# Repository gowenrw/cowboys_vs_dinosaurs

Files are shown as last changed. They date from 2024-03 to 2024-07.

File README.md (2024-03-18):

# cowboys_vs_dinosaurs

Cowboys vs Dinosaurs Badge Artifacts

This is a DEFCON Indie badge created for DC32.

This is where all the files for the Badge will be stored.

This includes code and art and cad and fab files.  All the things.

## File Structure

This is the file structure of this repository

* [/](/README.md) - YOU ARE HERE
* [/art/](./art/) - Artwork and other graphics created by this project
  * [/art/inspiration/](./art/inspiration/) - Art and graphics pulled f6 other sources used as inspiration for this project
  * [/art/fonts/](./art/fonts/) - Fonts used in art and graphics
* [/code/](./code/) - All project related Code / Firmware
* [/docs/](./docs/) - Documentation created by this project including web pages
* [/eda/](./eda/) - Electronic Design Automation files (i.e. KiCad)
  * [/eda/cowboys_vs_dinos/](./eda/cowboys_vs_dinos/) - KiCad 7.x project folder for the cowboys_vs_dinos PCB
* [/reference_parts/](./reference_parts/) - Documentation pulled from other sources related to components
* [/README.md](/README.md) - This File
* [/LICENSE](/LICENSE) - Currently set to MIT

Note: the reference_parts directory is a link to a submodule repository.
To add it use the following cmd after cloning this:
```
git submodule update --init --recursive
```
If adding for the first time (i.e., it is not linked in the remote master) use this:
```
git submodule add https://github.com/gowenrw/reference_parts reference_parts
```
This will make a link to the current commit of that repo.
To update it to a newer commit after its been added use this cmd:
```
git submodule update --remote
```

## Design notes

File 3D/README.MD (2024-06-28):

# 3D Files

## Badge bumper

The badge bumper is a simple 3d print that sandwiches between the two PCBs. It is designed to press onto the standoff nuts to keep it in place.

This bumper provides a few useful features:
- Prevents things from dropping into the well of the badge
- When printed with a translucent material, allows for diffusion of the LED lights

When printing, we currently recommend a low infill, around 5%, and a recilinear infill or similar geometry as opposed to infill such as Gyroidal which will diffuse too much light internally.

We do not have specific print settings for this, but the part is designed to print as easily as possible.

-@hon1nbo

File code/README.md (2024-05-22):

# Code

This is where all the project related Code / Firmware is located

# File Structure

This is the file structure of this repository

* [/](/README.md) - Home
* [/code/](/code/) - YOU ARE HERE

# Arduino IDE/CLI

The code presented here is mostly Arduino code.

In order to use this code and push new code to the ESP32 on the badge we recommend using the Arduino IDE/CLI software.
This can be downloaded for various platforms at [arduino.cc](https://www.arduino.cc/en/software).

The Arduino IDE UI will require some manual configuration to work with the badge ESP32 and our code.

The Arduino CLI can be used instead and allows for scripting much of the initial setup and use of whichever IDE you like (in my case I use VSCode).

# Arduino Versions

These are the Arduino IDE and CLI versions we have tested the code with:

* Arduino IDE v 2.3.2
  * [Windows MSI Link](https://downloads.arduino.cc/arduino-ide/arduino-ide_2.3.2_Windows_64bit.msi)
  * [Linux 64bit AppImage Link](https://downloads.arduino.cc/arduino-ide/arduino-ide_2.3.2_Linux_64bit.AppImage)
  * [MacOS ARM64bit DMG Link](https://downloads.arduino.cc/arduino-ide/arduino-ide_2.3.2_macOS_arm64.dmg)
  * [Installation Instructions](https://docs.arduino.cc/software/ide-v2/tutorials/getting-started/ide-v2-downloading-and-installing)
* Arduino CLI v 0.35.3
  * [Windows MSI Link](https://github.com/arduino/arduino-cli/releases/download/v0.35.3/arduino-cli_0.35.3_Windows_64bit.msi)
  * [Linux 64bit Tarball Link](https://github.com/arduino/arduino-cli/releases/download/v0.35.3/arduino-cli_0.35.3_Linux_64bit.tar.gz)
  * [MacOS ARM64bit Tarball Link](https://github.com/arduino/arduino-cli/releases/download/v0.35.3/arduino-cli_0.35.3_macOS_ARM64.tar.gz)
  * [Installation Instructions](https://arduino.github.io/arduino-cli/0.35/installation/)

# Quickstart

If you want to jump right in and start compiling and uploading code using the Arduino CLI and the scripts provided then checkout the [QUICKSTART page](QUICKSTART.md).

# Arduino IDE setup and use

Some additional setup is required to use the Arduino IDE with the ESP32 on the badge:

* Add the ESP32 boards manager URL in preferences
  * Under File->Preferences find the "Additional boards manager URLs" section and add the following
  * https://espressif.github.io/arduino-esp32/package_esp32_index.json
  * Then click OK and close the IDE.  When it is reopened it wil download the ESP32 board definitions.
* Select the board "ESP32 Dev Module"
  * You need to select a board to associate with the code even if that board is not connected
  * In the "Select Board" dropdown, choose "ESP32 Dev Module" from the list
  * The first time you do this it may download some addiotional software.
* Connect the ESP32 via USB cable and select the COM port if it is not autodetected
  * In most cases it should autodetect the port
  * Sometimes on first connect you need to help it by going to Tools->Port and choosing the port
* This code exceeds the normal partition size so make sure you select the Minimal SPIFFS Partition type
  * This setting can be found under Tools -> Partition Scheme
* This code uses the AdaFruit NeoPixel library which needs to be installed
  * The library can be installed via the Arduino IDE library manager or manually
  * Installation instructions can be found at [the adafruit neopixel github page](https://github.com/adafruit/Adafruit_NeoPixel)

Once the Arduino IDE environment has been set up you can simply open one of the sketches here, make whatever changes you like, then compile and upload the code to the badge.

# Arduino CLI

In an effort to bring portability to the code here (since this is lacking in the Arduino 2.x IDE) we will be providing a local configuration file for the Arduino CLI and scripts to make use of it.

While we cannot ensure this will work on all systems, the files provided should at a minimum help you configure your local environment.

## Using the CLI Local Config

The arduino cli will use a global default config if a config file is not specified.

A local config file is provided named ```arduino-cli.yml``` which uses relative path references for the data and staging and build and user area that Arduino CLI should use.

These directories are local to the repository code directory and the CLI will install all its needed files here instead of in the various places it usually defualts to on differnt systems.

While this might duplicate many files on your system if they are already installed in default locations, it provides a consistent cross platform way of knowing exactly what libraries, headers, etc., that Arduino will use in the compilation of your code.

NOTE that the .gitignore for this repository has been set up to ignore the local directories used to store the core and library files to prevent these files from accidentally getting uploaded to github.

To use the Arduino CLI with this local config file simply add the ```--config-file arduino-cli.yml``` argument to each CLI command.

For example, the command below uses the local config file and will dump the current config to the screen
```
arduino-cli --config-file arduino-cli.yml config dump
```

## Setup for CLI

There are a few things that need to be done to setup the Arduino CLI for use with the badge ESP32 and our code.

The ESP32 board core files must be loaded as well as any libraries the code will use.

To simplify this setup we have created setup bash script named ```cli-setup.sh``` that can be run on Linux and Windows (via Git Bash for Windows).

To perform the CLI setup via the script execute it in the code directory
```
bash ./cli-setup.sh
```

This script will save any std_out and std_err output to a file named ```arduino_cli_setup.log``` which you can review if you are having issues.

To perform the CLI setup manually without this script you can use the commands outlined below.

### Installing the ESP32 board core for CLI

Since the config is specifying a third party core for the ESP32 we need to pull an initial index from it.  This search command will pull that index.
```
arduino-cli --config-file arduino-cli.yml core search esp32
```

Next we need to install the ESP32 board core files using this command.
```
arduino-cli --config-file arduino-cli.yml core install esp32:esp32
```

If the ESP32 board core files were already installed the above will simply say already installed.

To update the core file indexs to check for newer versions of previously installed cores, use the following command
```
arduino-cli --config-file arduino-cli.yml core update-index
```

To upgrade any previously installed cores use the following command
```
arduino-cli --config-file arduino-cli.yml core upgrade
```

### Installing the Neopixel Library

This code uses the AdaFruit NeoPixel library which needs to be installed

If this is the first time we are installing a library we will need the indexes so this search command will get them
```
arduino-cli --config-file arduino-cli.yml lib search 'Adafruit NeoPixel'
```

Next we need to install the Adafruit NeoPixel library files with this command
```
arduino-cli --config-file arduino-cli.yml lib install 'Adafruit NeoPixel'
```

If the Adafruit NeoPixel library files were already installed the above will simply say already installed.

To upgrade a previously installed version of this library use the following command
```
arduino-cli --config-file arduino-cli.yml lib upgrade 'Adafruit NeoPixel'
```

### Installing Other Libraries

In addition to the Neopixel Library above the CTF portion of our code requires a few more libraries.

These should be installed using the same steps as above.

This is the list of additional libraries needed

* "AsyncTCP"
* "ESPAsyncWebSrv"
* "DNSServer"

## Connect badge ESP32 board via CLI

The following command will dump a list of all available board cores installed
```
arduino-cli --config-file arduino-cli.yml board listall
```

Make sure the ESP32 we are using on the badge is in that list
```
  ESP32 Dev Module                 esp32:esp32:esp32
```

If it is not then retry the CLI setup to install the core files.

Next we will connect the badge ESP32 to our machine using a USB C cable
and check if the CLI can see it.

The following command will list all the connected boards the CLI sees
```
arduino-cli --config-file arduino-cli.yml board list
```

This will show the detected COM port and board type (which may be Unknown)
```
  Port Protocol Type                Board Name FQBN Core
  COM4 serial   Serial Port (USB)   Unknown
```

Don't worry if the board FQBN shows up as Unknown since we can set that

Take note of the COM port since we will need that to communicate with it later

## Compile code via CLI

At this point we should be ready to compile and upload code to the badge ESP32 board.

In the following examples we will be referencing the sketch ```cvd_02``` code so you will need to change this for whichever sketch you wish to use.

The following command will compile the named sketch for use with our board fqbn
```
arduino-cli --config-file arduino-cli.yml compile --fqbn esp32:esp32:esp32 --build-path _build --export-binaries cvd_02 --build-property build.partitions=min_spiffs --build-property upload.maximum_size=1966080
```

The arg ```--build-path _build``` is optional to have it put all build artifacts here instead of temp for ease of troubleshooting.

The arg ```--export-binaries``` will save the final binary files into ```<sketch_name>/build/<fqbn>/``` for use by upload.

The build property args ```--build-property build.partitions=min_spiffs --build-property upload.maximum_size=1966080``` make sure that the partition size and upload size are set properly.
Our code is THIC and wont fit in the default partition size.

When the CLI compile is run it should show you compile stats and/or errors similar to this
```
  Sketch uses 1827197 bytes (92%) of program storage space. Maximum is 1966080 bytes.
  Global variables use 48884 bytes (14%) of dynamic memory, leaving 278796 bytes for local variables.
  Maximum is 327680 bytes.
  Used library        Version Path
  Adafruit NeoPixel   1.11.0  .\code\libraries\Adafruit_NeoPixel
  WiFi                2.0.0   .\code\_data\packages\esp32\hardware\esp32\2.0.11\libraries\WiFi
  AsyncTCP            1.1.4   .\code\libraries\AsyncTCP
  DNSServer           2.0.0   .\code\_data\packages\esp32\hardware\esp32\2.0.11\libraries\DNSServer
  ESPAsyncWebSrv      1.2.6   .\code\libraries\ESPAsyncWebSrv
  FS                  2.0.0   .\code\_data\packages\esp32\hardware\esp32\2.0.11\libraries\FS
  Used platform Version Path
  esp32:esp32   2.0.11  .\code\_data\packages\esp32\hardware\esp32\2.0.11
```

### Script to Compile code via CLI

To simplify the above we have created a bash script named ```cli-compile.sh``` that takes a single command line argument of the sketch name.

To perform the compile via the script execute it in the code directory
```
bash ./cli-compile.sh cvd_02
```

## Upload code via CLI

Now we are ready to upload the binary we compiled to the badge ESP32 board.

Note that the binary file needed is saved to ```<sketch_name>/build/<fqbn>/``` and will be named ```<sketch_name>.ino.bin```
The code we have written here may include binaries which can be used without compiling and if you make changes and compile then these files should be overwritten.

The following command will upload the named sketch binary to the badge
```
arduino-cli --config-file arduino-cli.yml upload -p COM4 --fqbn esp32:esp32:esp32 --input-file cvd_02/build/esp32.esp32.esp32/cvd_02.ino.bin
```

NOTE: Saving the compiled binary in a defined place and uploading from an input file allows for quickly changing between different code without the need to compile each again.

It should show you upload stats and/or errors
```
  esptool.py v4.5.1
  Serial port COM4
  Connecting....
  Chip is ESP32-D0WD-V3 (revision v3.0)
  Features: WiFi, BT, Dual Core, 240MHz, VRef calibration in efuse, Coding Scheme None
  Crystal is 40MHz
  MAC: a8:42:e3:47:f0:50
  Uploading stub...
  Running stub...
  Stub running...
  Changing baud rate to 921600
  Changed.
  Configuring flash size...
  Flash will be erased from 0x00001000 to 0x00005fff...
  ...
  Compressed 18960 bytes to 13073...
  Writing at 0x00001000... (100 %)
  Wrote 18960 bytes (13073 compressed) at 0x00001000 in 0.3 seconds (effective 538.9 kbit/s)...
  Hash of data verified.
  ...
  Compressed 732656 bytes to 475614...
  Writing at 0x00010000... (3 %)
  Writing at 0x0001c1bd... (6 %)
  ...
  Writing at 0x000bcec0... (96 %)
  Writing at 0x000c2b72... (100 %)
  Wrote 732656 bytes (475614 compressed) at 0x00010000 in 6.3 seconds (effective 925.8 kbit/s)...
  Hash of data verified.
  Leaving...
  Hard resetting via RTS pin...
```

### Script to Upload code via CLI

To simplify the above we have created a bash script named ```cli-upload.sh``` that takes two command line arguments of the sketch name and serial port.

To perform the compile via the script execute it in the code directory
```
bash ./cli-upload.sh cvd_02 COM4
```

## Monitor Serial Output

To monitor the serial output you can use the arduino-cli or your favorite serial app.

The following command will list all the connected boards so you can get the serial port
```
arduino-cli --config-file arduino-cli.yml board list
```

The arduino-cli monitor command with serial port (from above) and baud config can be used like this:
```
arduino-cli monitor --port COM4 --config baudrate=115200
```

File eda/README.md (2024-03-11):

# Electronic Design Automation

This is where all the Electronic Design Automation files for the PCB(s) will be stored.
The EDA used is KiCad 7.x unless otherwise specified.

The KiCad projects have been configured to use local libraries for long term sustainability per the best practices listed [HERE](https://hackaday.com/2017/05/18/kicad-best-practises-library-management/) and elsewhere.

## File Structure

This is the file structure of this repository

* [/](/README.md) - Home
* [/eda](/eda/) - YOU ARE HERE
  * /eda/<project>/ - KiCad project folder for the named project PCB(s)
    * ./3d_models/ - This directory contains footprint 3d model files
    * ./gerber/ - This directory contains gerber formatted files for manufacturing
    * ./lib_fp/ - This directory contains footprint module directories
    * ./lib_sh/ - This directory contains schematic library files
    * ./snapshots/ - This directory contains prints of schematic / cad files and images of preview / final product

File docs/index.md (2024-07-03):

---
layout: default
---

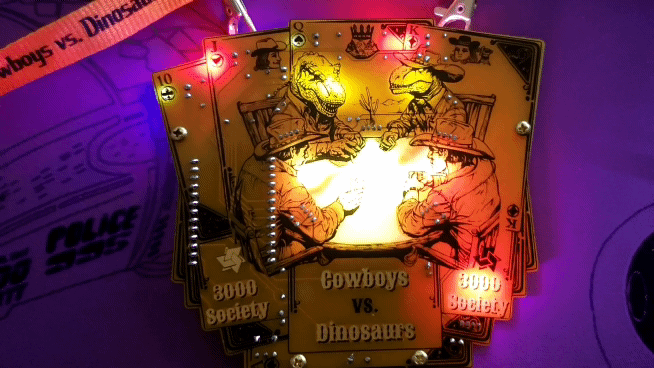
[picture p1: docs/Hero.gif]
Hero Image


# Cowboys vs Dinosaurs Badge

Welcome to the Cowboys vs Dinosaurs Badge website.

This badge was designed for the 3000 Society conference in May 2024.
It will also be made available at the DEFCON 32 conference in Aug 2024.

On this page you will find all the details about this badge including an operations guide, an assembly guide (for those building the badge from a kit), and a detailed review of the art and cicuit design and pcb design.

-- [@alt_bier](https://twitter.com/alt_bier)  - [My Contact Info](https://gowen.net/about)

---

Touch Image

# Details

The badge theme was based on the 3000 Society conference theme of "Cowboys vs Dinosaurs".
Since this is a gaming conference I thought it was apppropriate to have them facing off at a card game with a playing card background.

This badge includes an ESP32 Wemos Lolin32 development board, six neopixel addressable LEDs, six traditional one color LEDs, and five capacitive touch areas, all powered by a LIPO battery.

Since the ESP Dev board has an embedded battery charge circuit the schematic for the badge is fairly simple.
The PCB layout and tracing was a challenge due to all the solder mask voids and capacitive touch areas.

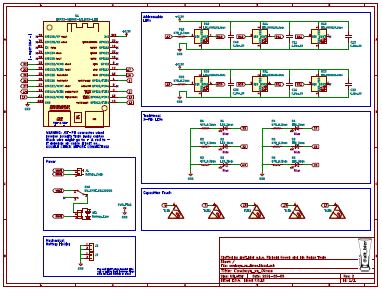
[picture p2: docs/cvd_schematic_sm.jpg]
Schematic

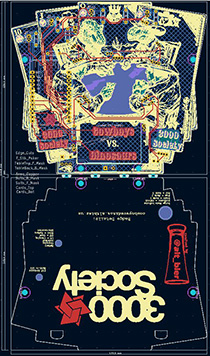
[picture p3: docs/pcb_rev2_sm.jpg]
PCB


# Kit Assembly

Assembly Instructions for the Cowboys vs Dinosaurs Badge kit can be found here: [Cowboys vs Dinosaurs Badge Assembly Instructions](assembly.md)

An assembly video can be found here:
[Cowboys vs Dinosaurs Badge Assembly Video](https://www.youtube.com/watch?v=riOWy_HshVY&ab_channel=alt_bier_hacker)

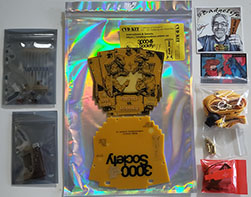
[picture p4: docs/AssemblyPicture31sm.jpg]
Badge_Kit


# Badge Operations

Here are the basics for operating the badge.

## Power Switch and Battery Charging

This badge uses an ESP32 Development board with a USB-C connector that is connected to and powered by a LIPO rechargeable battery.

The power switch on the badge is a direct cutoff to the LIPO battery.
So the switch must be in the ON position in order to charge the battery from the dev board.

The switch is in the OFF position when it is closer to the battery.

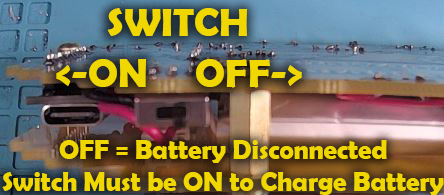
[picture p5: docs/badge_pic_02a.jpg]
Power Switch Image


To charge the battery follow these steps:
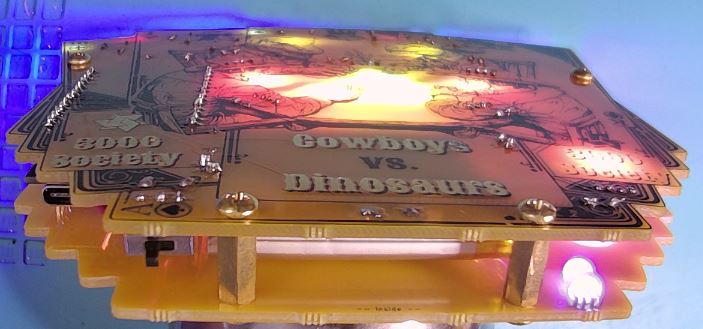
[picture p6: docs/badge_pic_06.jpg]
Power ON Image
* Turn the power switch to ON which will power on the badge if the battery has any charge remaining.  But, even if the badge does not power on the switch should be in the ON position. 
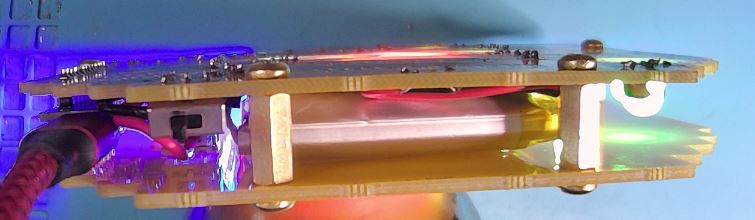
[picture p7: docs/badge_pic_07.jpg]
USB Cable Image
* Plug in a USB-C cable to the badge dev board and apply power either from a PC or wall charger. 
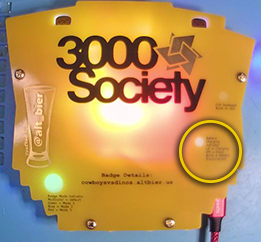
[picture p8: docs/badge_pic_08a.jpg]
Charge Indicator Image
* On the back of the badge you should see the battery charge indicator light lit up.  If it is not then repeat the first two steps to try again.  This indicator light should flash if it does not see a battery connected and will turn off when a connected battery is fully charged. 
* It should take about 3 to 4 hours to fully charge a battery from fully discharged at which point the battery charge indicator light will turn off.
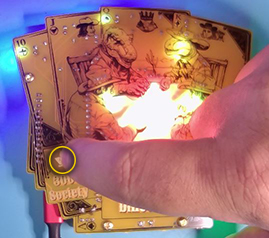
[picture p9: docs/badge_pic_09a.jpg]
Logo Press Image
* Since it can be annoying to have the badge flashing all its LEDs while charging we added a LED-Off mode that can be activated by pressing on the logo button for a long press of about 20 seconds. 
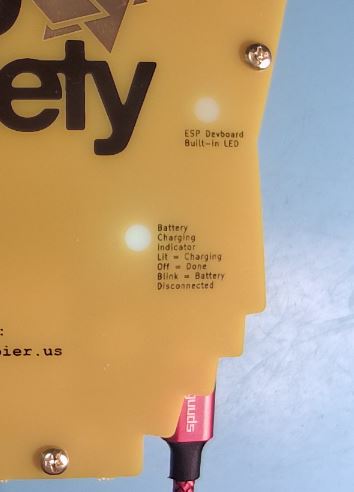
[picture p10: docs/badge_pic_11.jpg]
LED Off Mode Image
* In the LED-Off mode all the badge LEDs will turn off except for the two on the ESP dev board.  The battery charge indicator light should be on if it charging and the on-board LED will flash once every 20 seconds or so.  The flashing LED is there to tell you the badge is still powered on even if the charge is done and the charge light turns off. This LED mode can be disabled by long pressing the logo again or by power cycling the badge (including disconnecting the USB) 

## Touching Cowboys - Flush Game

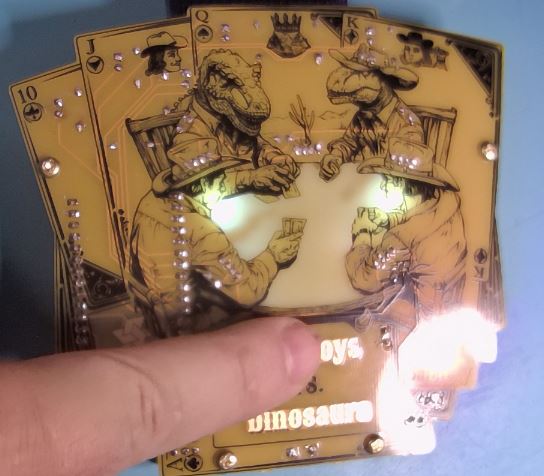
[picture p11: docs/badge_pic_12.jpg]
Cowboys Image
Pressing the word "Cowboys" will light up the two cowboys faces for a few seconds before returning to the default LED mode. 

Holding a long press of 20 seconds on the word "Cowboys" will enter the Flush game mode.
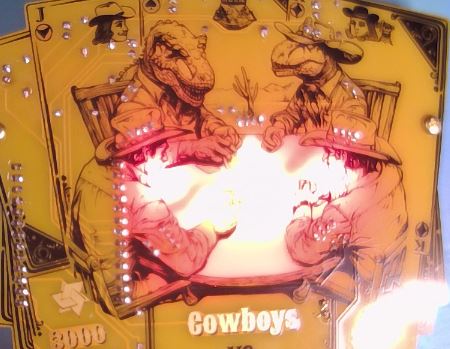
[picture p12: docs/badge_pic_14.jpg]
Flush Image
This is a simple game that will light the five LEDs in the table area with different colors each time you press "Cowboys" and it will keep them all lit if all five LEDs have matching colors indicating you got a flush and won.  This LED mode can be disabled by long pressing "Cowboys" again or by power cycling the badge. 

## Touching Dinosaurs - Reaction Game

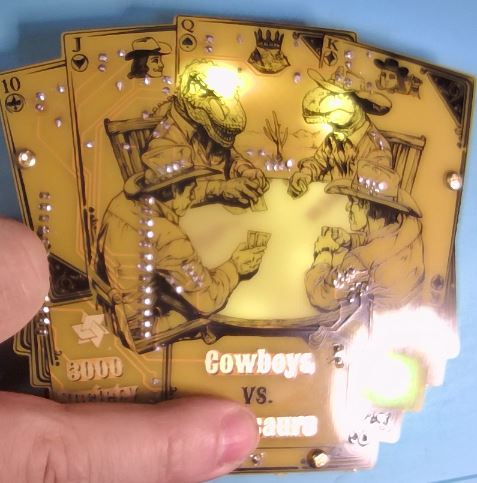
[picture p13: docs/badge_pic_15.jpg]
Dinosaurs Image
Pressing the word "Dinosaurs" will light up the two dinosaurs faces for a few seconds before returning to the default LED mode. 

Holding a long press of 20 seconds on the word "Dinosaurs" will enter the Reaction Time game mode.
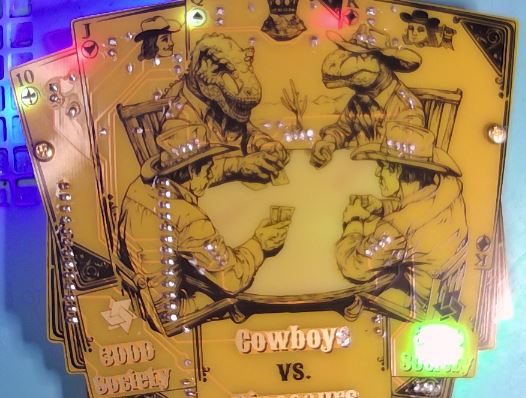
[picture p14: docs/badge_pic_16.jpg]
Reaction Image
This is a simple game that turn on each of the four card LEDs one at a time before turning them off again.  Pressing "Dinosaurs" will stop the LEDS in thier current positions for a few seconds.  The goal of the game is to try to stop it with all four LEDs lit. This LED mode can be disabled by long pressing "Dinosaurs" again or by power cycling the badge. 

## Touching 3000

Pressing the word "3000" will flash the center lights briefly in a boop effect.
This was added in code revision 2 so if this does nothing then you are running an older code version.

## Touching Society - Adventure Game

Pressing and holding the word "Society" for a long press of 20 seconds you will enter the Adventure game.
This will light the status LED red and then spin up a wireless access point with the name "cvd-badge-<MAC>" and a web server on 192.168.1.31
Connect to the access point which is open and does not require a password, then browse http://192.168.1.31 to start the adventure.
This is a simple choose your own adventure game.
This was added in code revision 2 so if this does nothing then you are running an older code version.

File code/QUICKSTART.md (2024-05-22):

# Code Quickstart

Notes:

* You will need Arduino CLI Installed and a Bash shell (on Windows Git Bash is provided by Git for Windows)
* The CTF code is a precompiled library so you cant change that for now, source to be released after defcon
* The current code that is loaded on the badge is the sketch named ```cvd_02```

## Setting up Arduino CLI environment

Follow these steps:

* Change directory to the code directory if you arent already there
* Run the following command preceding it with ```bash``` if needed by your OS
  * ```./cli-setup.sh```
* If it completes without errors then setup is complete
  * If you have errors then refer to the main README doc or script file to try the steps manually

## Compiling Code

Once you have made whatever changes you wanted to the code here is how we compile it.

* Change directory to the code directory if you arent already there
* Run the following command preceding it with ```bash``` if needed by your OS changing the sketch name if needed
  * ```./cli-compile.sh cvd_02```
* If it completes without errors then the compile is complete
  * If you have errors then read what they are and make the appropriate changes to your code

## Upload Code

Once the code has been compiled we can upload it to the badge.

Follow these steps:

* Change directory to the code directory if you arent already there
* Run the following command
  * ```arduino-cli --config-file arduino-cli.yml board list```
* Take note of the serial port name of the connected board 
* Run the following command preceding it with ```bash``` if needed and changing the serial port to above
  * ```./cli-upload.sh cvd_02 COM6```

## Serial Monitor

Once the code has been uploaded you can use the serial monitor to look for any text the code is sending.

* Run the following command changing the serial port to what board list showed above
  * ```arduino-cli monitor --config baudrate=115200 --port COM6```

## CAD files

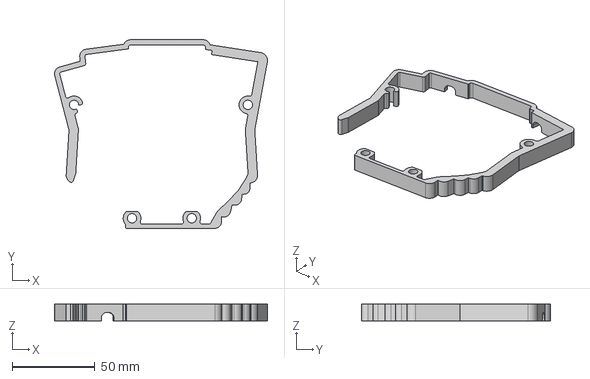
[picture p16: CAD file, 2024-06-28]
3D/dc32_cowbows_dinosaurs_bumper.step
128.9 x 114.1 x 10.2 mm

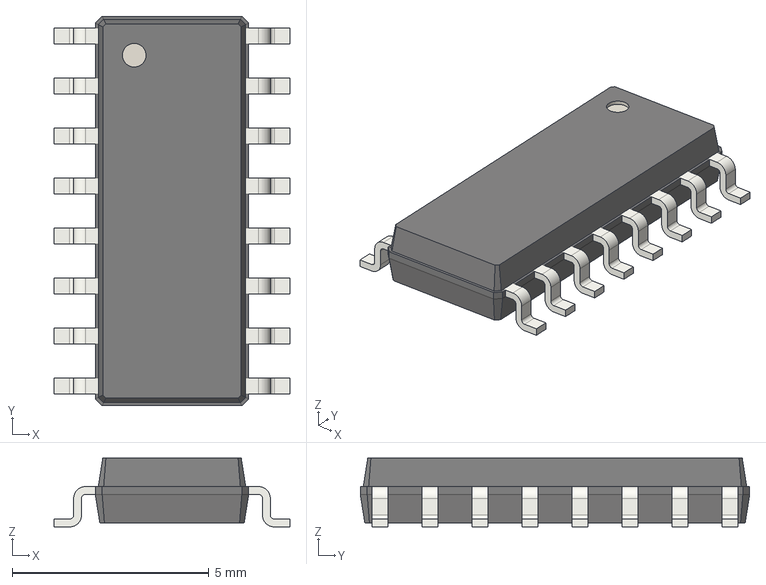
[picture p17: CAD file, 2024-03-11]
eda/cowboys_vs_dinos/3d_models/SOIC-16_3.9x9.9mm_P1.27mm.step
6.00 x 9.90 x 1.75 mm

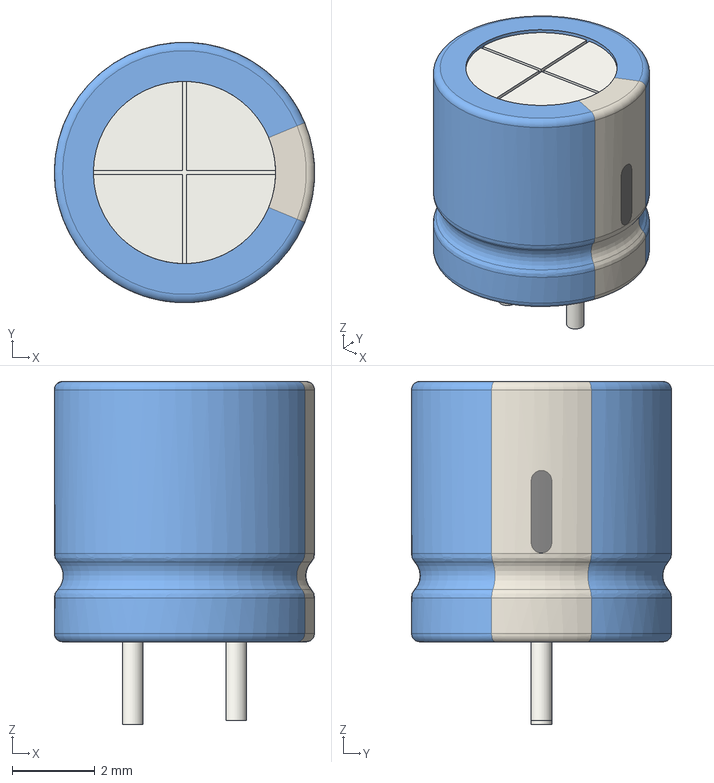
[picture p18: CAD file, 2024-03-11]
eda/cowboys_vs_dinos/3d_models/CP_Radial_D6.3mm_P2.50mm.step
6.30 x 6.30 x 8.30 mm

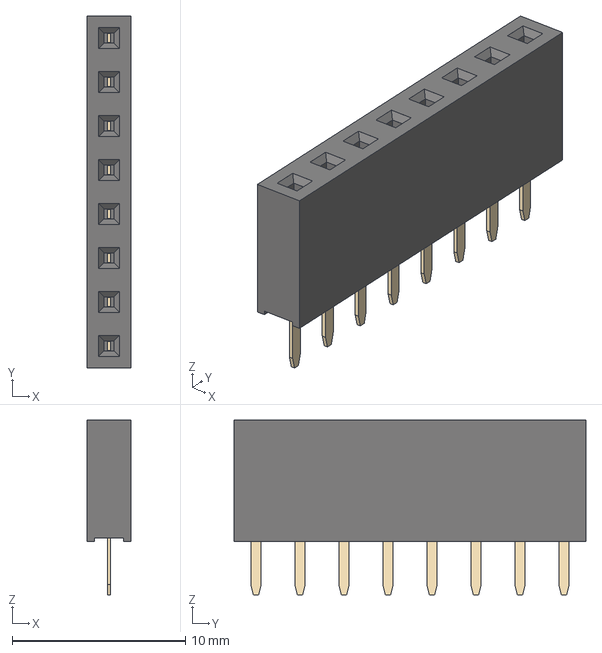
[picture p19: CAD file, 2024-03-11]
eda/cowboys_vs_dinos/3d_models/PinSocket_1x08_P2.54mm_Vertical.step
2.54 x 20.3 x 10.1 mm

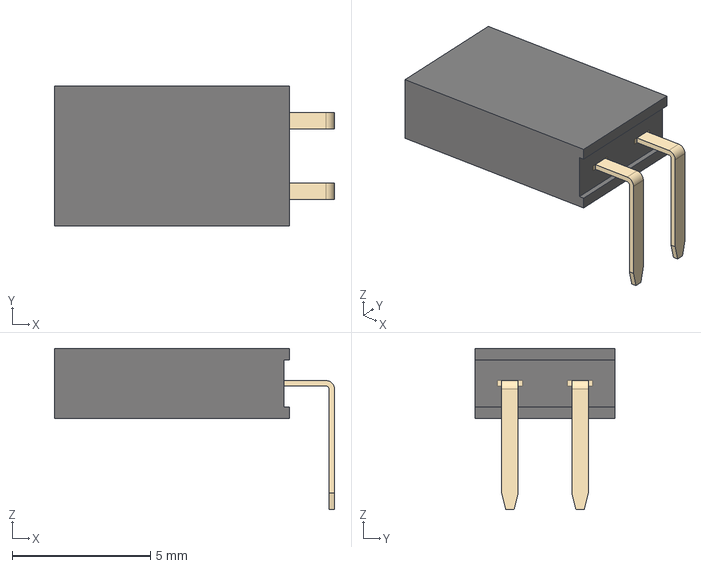
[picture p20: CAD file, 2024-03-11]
eda/cowboys_vs_dinos/3d_models/PinSocket_1x02_P2.54mm_Horizontal.step
10.1 x 5.08 x 5.84 mm

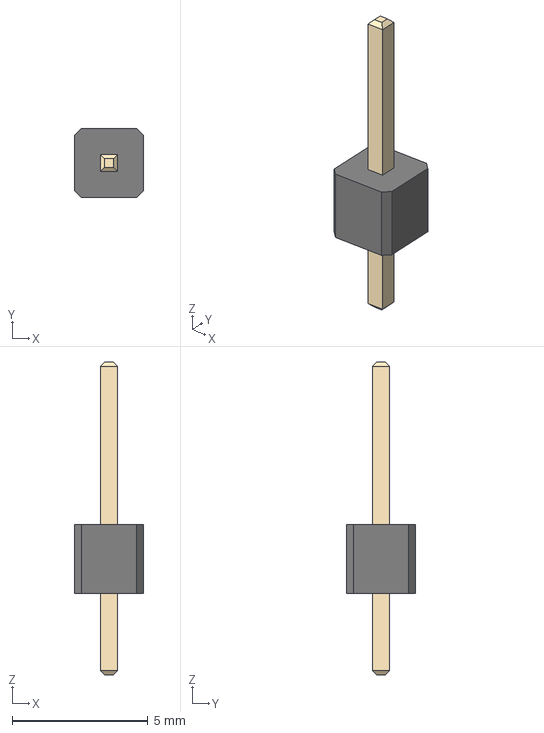
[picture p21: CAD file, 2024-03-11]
eda/cowboys_vs_dinos/3d_models/PinHeader_1x01_P2.54mm_Vertical.step
2.54 x 2.54 x 11.5 mm

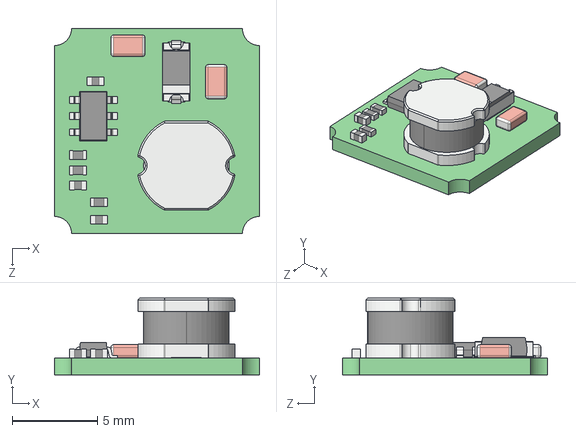
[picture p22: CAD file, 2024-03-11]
eda/cowboys_vs_dinos/3d_models/CUI_PXO7803-500-M-TR.step
12.0 x 4.50 x 12.0 mm

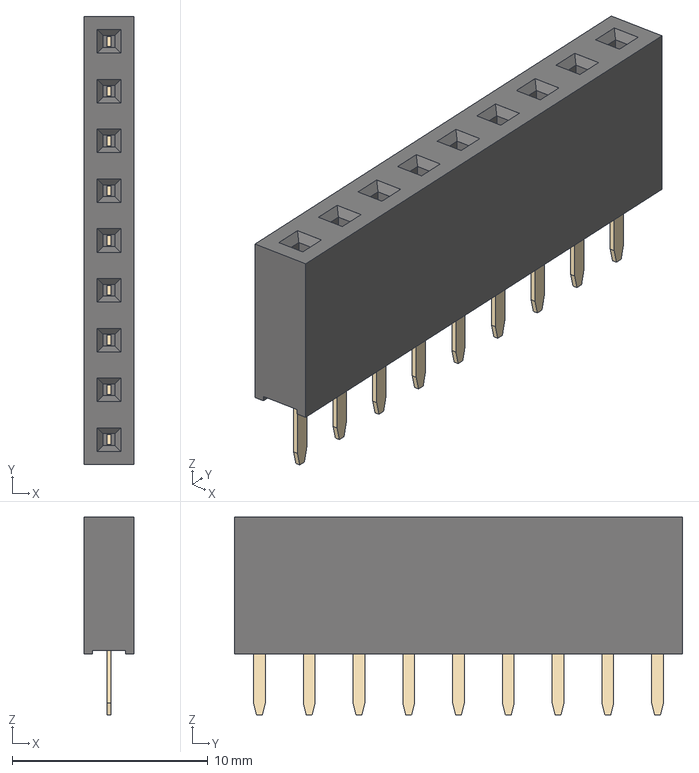
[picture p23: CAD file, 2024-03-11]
eda/cowboys_vs_dinos/3d_models/PinSocket_1x09_P2.54mm_Vertical.step
2.54 x 22.9 x 10.1 mm

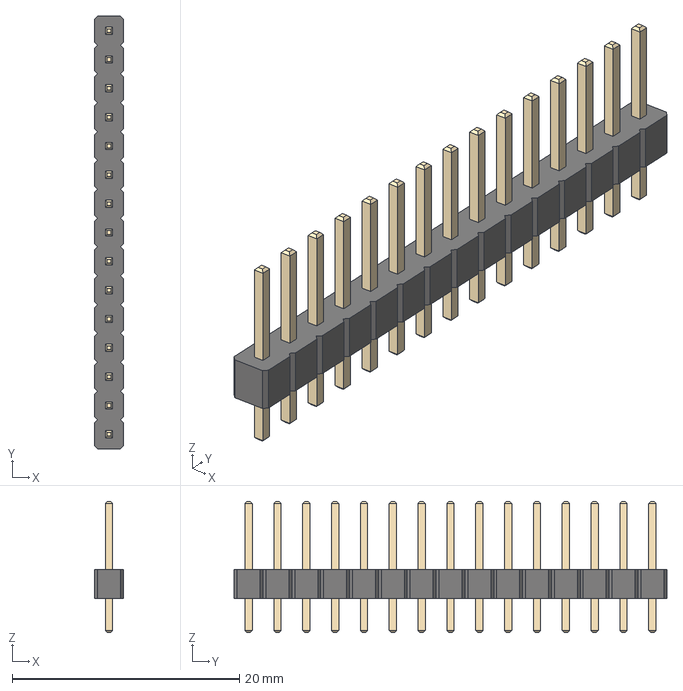
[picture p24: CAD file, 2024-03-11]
eda/cowboys_vs_dinos/3d_models/PinHeader_1x15_P2.54mm_Vertical.step
2.54 x 38.1 x 11.5 mm

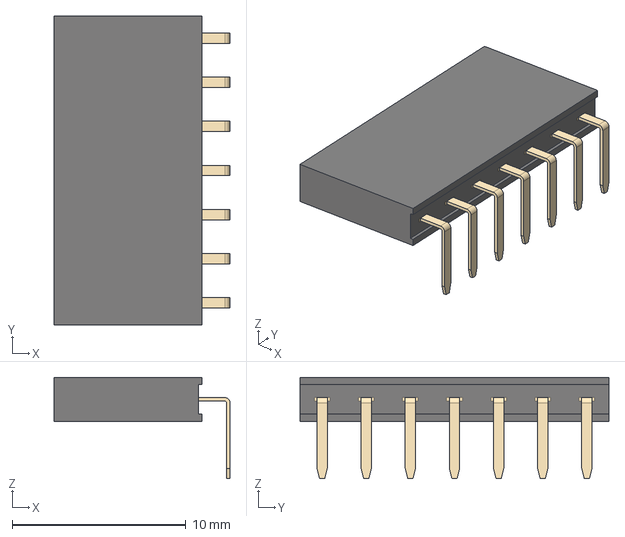
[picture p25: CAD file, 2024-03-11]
eda/cowboys_vs_dinos/3d_models/PinSocket_1x07_P2.54mm_Horizontal.step
10.1 x 17.8 x 5.84 mm

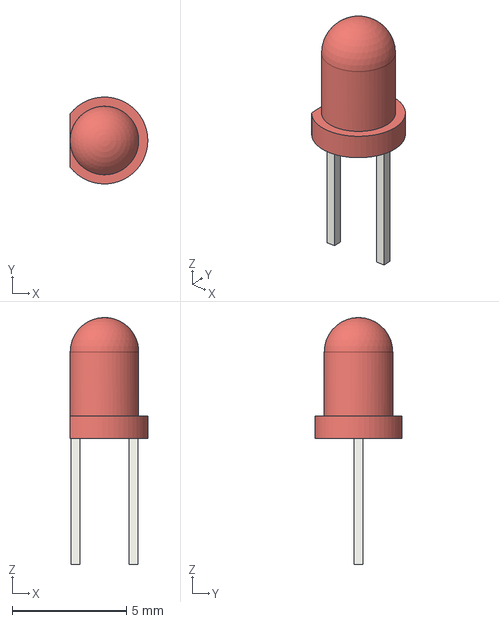
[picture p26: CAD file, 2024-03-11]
eda/cowboys_vs_dinos/3d_models/LED_D3.0mm.step
3.40 x 3.80 x 10.8 mm

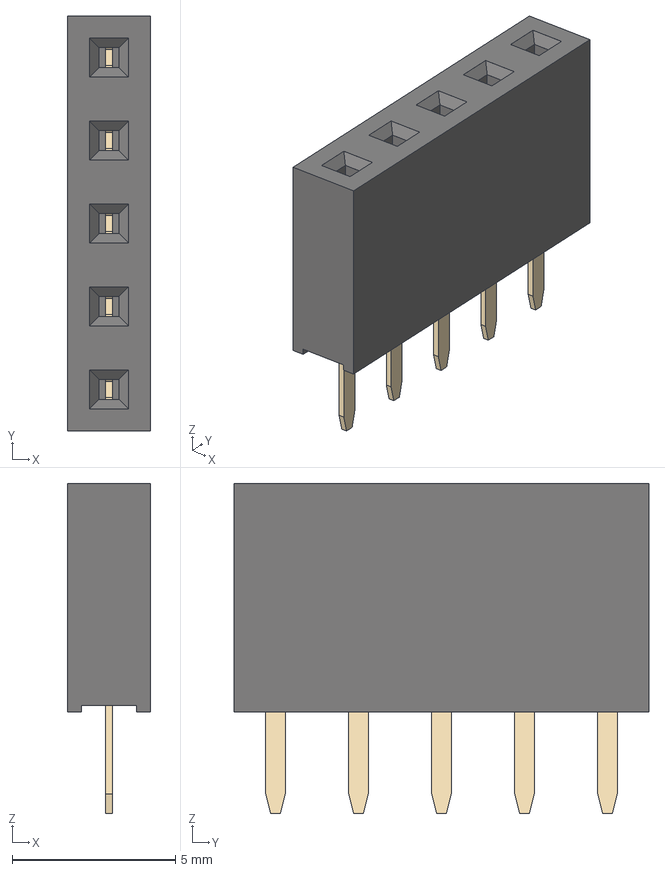
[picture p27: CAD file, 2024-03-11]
eda/cowboys_vs_dinos/3d_models/PinSocket_1x05_P2.54mm_Vertical.step
2.54 x 12.7 x 10.1 mm

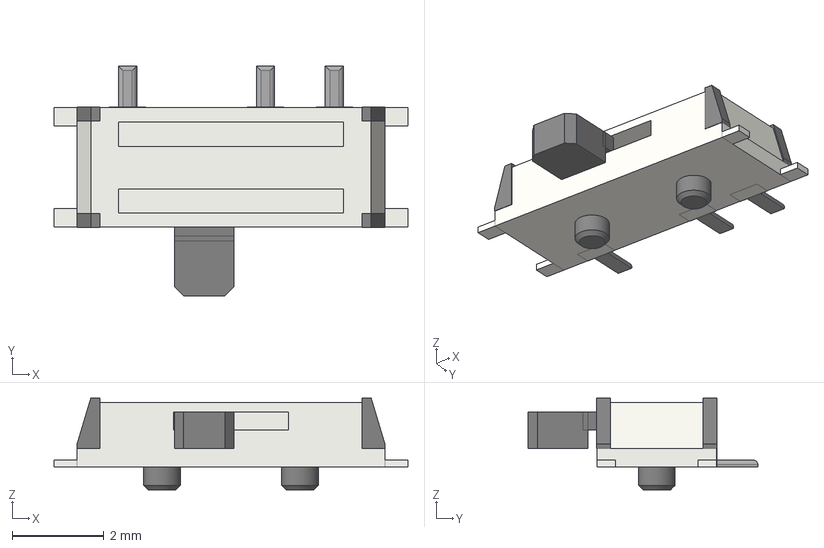
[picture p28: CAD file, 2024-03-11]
eda/cowboys_vs_dinos/3d_models/SW_SPDT_PCM12.step
7.70 x 5.00 x 2.00 mm

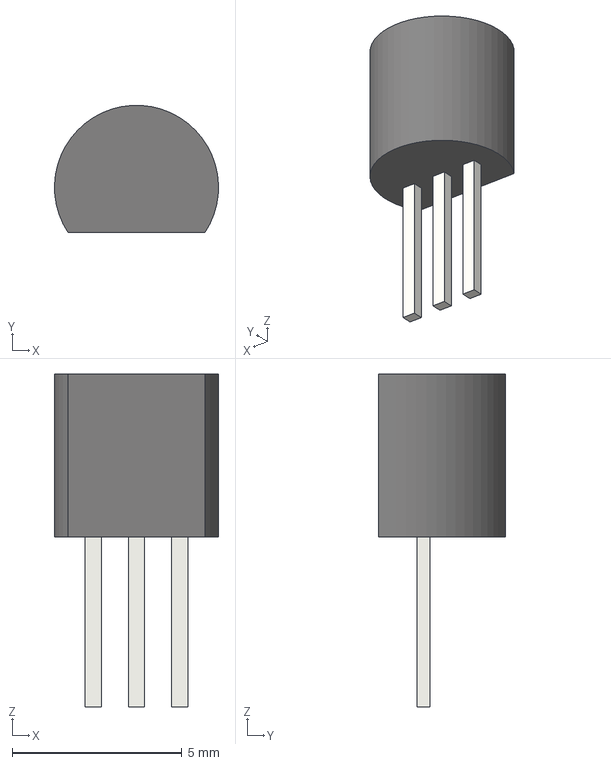
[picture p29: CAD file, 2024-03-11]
eda/cowboys_vs_dinos/3d_models/TO-92_Inline.step
4.83 x 3.74 x 9.80 mm

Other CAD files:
eda/cowboys_vs_dinos/3d_models/PinSocket_1x15_P2.54mm_Vertical.step
eda/cowboys_vs_dinos/3d_models/PinSocket_1x02_P2.54mm_Vertical.step
eda/cowboys_vs_dinos/3d_models/LED_0603_1608Metric.step
eda/cowboys_vs_dinos/3d_models/Battery_Holder_CR2032_BS-2-1.stp
3D/dc32_cowbows_dinosaurs_bumper.stl
eda/cowboys_vs_dinos/3d_models/BatteryHolder_2466_1xAAA.step
eda/cowboys_vs_dinos/3d_models/BatteryHolder_2468_2xAAA.step
eda/cowboys_vs_dinos/3d_models/Battery_Holder_3xAAA_Simple.step
eda/cowboys_vs_dinos/3d_models/CP_Radial_D5.0mm_P2.00mm.step
eda/cowboys_vs_dinos/3d_models/C_0603_1608Metric.step
eda/cowboys_vs_dinos/3d_models/C_0805_2012Metric.step
eda/cowboys_vs_dinos/3d_models/C_1206_3216Metric.step
eda/cowboys_vs_dinos/3d_models/C_Disc_D3.0mm_W2.0mm_P2.50mm.step
eda/cowboys_vs_dinos/3d_models/C_Rect_L4.6mm_W2.0mm_P2.50mm_MKS02_FKP02.step
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

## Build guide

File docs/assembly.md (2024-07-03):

---
layout: default
---

# Cowboys vs Dinosaurs Badge Kit Assembly Instructions

Welcome to the Cowboys vs Dinosaurs Badge kit assembly instructions.

This page will detail what comes in the badge kit and step by step instructions to build your badge. 

-- [@alt_bier](https://twitter.com/alt_bier)  - [My Contact Info](https://gowen.net/about)

## Badge Distribution Packages

The badges have been distributed in two different packages

* KIT - This is a kit that requires DIY soldering/assembly of all components
* ASS - This is a Fully Assembled ready to wear badge

## Component List

This is the list of components that are provided in the kit

* Main Kit Bag (20x30cm-8x12in Holographic) Containing:
  * 1x PCB panel (which breaks apart for top/front and bottom/rear PCBs) Note: The PCB might have broken apart during shipping, but this is not a problem as its required for assembly.
  * Small Component Bag #1 (4x5cm-1.5x2in Clear) Containing:
    * 4x Brass10mm Standoff and 2x M3 Screw set
  * Small Component Bag #2 (5x7cm-2x2.8in Red) Containing:
    * 1x Lipo Battery 103040
    * 1x JST mini PH Connector Wire
    * 2x Rubber Band Size #8 (1 req. 1 spare)
  * Small Component Bag #3 (8x8cm-3x3in Clear) Containing:
    * 1x Lanyand
  * Small Component Bag #4 (6x9cm-2.4x3.5in Mylar) Containing:
    * 1x ESP32 WeMos Lolin32 Dev Board
    * 2x Header Male 2.54mm 1x13 Pin Strip
  * Small Component Bag #5 (8x12cm-3.2x4,7in Mylar) Containing:
    * 6x WS2812D 5mm 4-Pin Addressable Neopixel LED
    * 2x White 3mm 2-pin LED
    * 2x Red 3mm 2-pin LED
    * 2x Blue 3mm 2-pin LED
    * 6x 100nF Ceramic Disc Capacitor
    * 8x 47 Ohm 6.2mm Metal Film Resistor
    * 1x SS12D00 3-Pin SPDT Right Angle Switch
    * 2x Header Male 2.54mm 1x2 Pin Right Angle Strip
  * 2x Sticker (Not Required for badge Assembly)

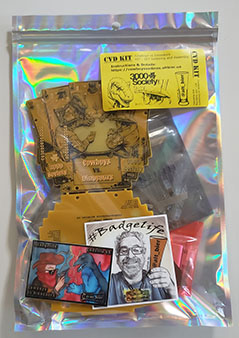
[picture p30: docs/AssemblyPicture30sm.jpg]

Badge_Kit

## Assembly Steps

* Break apart the PCBs on the mouse bites
  * To provide an even break line placing one PCB on a hard surface (like a desk) and pushing down on the other PCB works well
  * Break off the mouse bites from the PCB(s) that they are still attached to
  * Mini pliers are helpful but not required
  * The rough edges can be filed or sanded down if a smooth edge is preferred

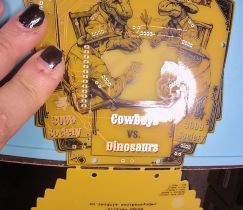
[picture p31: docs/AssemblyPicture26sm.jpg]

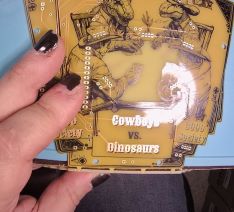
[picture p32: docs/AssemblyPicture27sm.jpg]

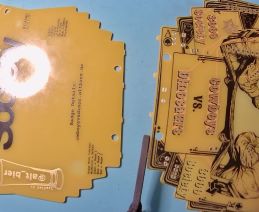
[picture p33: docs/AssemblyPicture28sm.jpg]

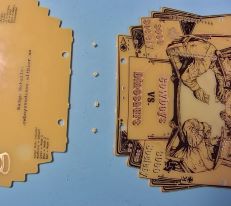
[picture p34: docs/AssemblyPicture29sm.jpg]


* Resistors
  * The eight 47-Ohm resistors are labeled R1-R6, R10 and R20
  * Resistors are non-polar so they can be placed in either direction.
  * Place all the resistors into the PCB bending thier legs outward to hold them in place
  * Solder all 16 resistor connections (both ends of the 8 resistors)
  * When cooled cut the component legs off at the top of the solder joints (do not cut into the solder joint)

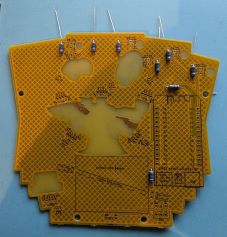
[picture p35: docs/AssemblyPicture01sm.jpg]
Resistors


* One Color 3mm 2 pin LEDs
  * The six traditional one color 2 pin LEDs are easy to solder but they need to be bent over for specific positioning on the PCB so be careful with placement
  * D4 & D6 - These are 3mm 2-pin RED LEDs
    * Place the LEDs in thier designated places on the PCB folding them over then bending legs out to hold in place
    * Make sure to align the LEDs properly using the silk guide to place short leg in square hole, folding the LEDs in the direction indicated to place the body of the LED over the solder mask void on the PCB
    * Solder all the LED connections
    * When cooled cut the component legs off at the top of the solder joints (do not cut into the solder joint)
  * D3 & D5 - These are 3mm 2-pin BLUE LEDs
    * Place the LEDs in thier designated places on the PCB folding them over then bending legs out to hold in place
    * Make sure to align the LEDs properly using the silk guide to place short leg in square hole, folding the LEDs in the direction indicated to place the body of the LED over the solder mask void on the PCB
    * Solder all the LED connections
    * When cooled cut the component legs off at the top of the solder joints (do not cut into the solder joint)
  * D1 & D2 - These are 3mm 2-pin WHITE LEDs
    * Place the LEDs in thier designated places on the PCB folding them over then bending legs out to hold in place
    * Make sure to align the LEDs properly using the silk guide to place short leg in square hole, folding the LEDs in the direction indicated to place the body of the LED over the solder mask void on the PCB
    * Solder all the LED connections
    * When cooled cut the component legs off at the top of the solder joints (do not cut into the solder joint)

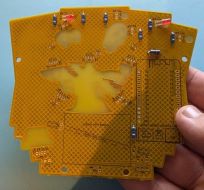
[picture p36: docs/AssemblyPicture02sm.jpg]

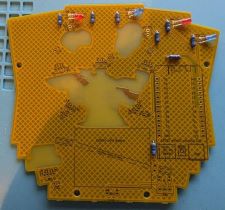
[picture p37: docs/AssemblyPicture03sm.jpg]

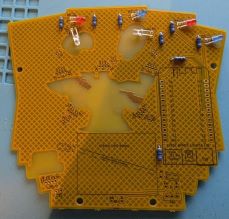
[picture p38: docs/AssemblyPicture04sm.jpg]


* Addressable Neopixel 5mm 4-Pin LEDs
  * The six Neopixel LEDs are a bit more difficult to solder given the pins are close together and they need to be bent over for specific positioning on the PCB so be careful with placement
  * D10, D11 & D12
    * Place the LEDs in thier designated places on the PCB folding them over then bending legs out to hold in place
    * Make sure to align the LEDs properly using the silk guide to place longest leg one position over from the square hole, folding the LEDs in the direction indicated to place the body of the LED over the solder mask void on the PCB
    * Solder all the LED connections
    * When cooled cut the component legs off at the top of the solder joints (do not cut into the solder joint)
  * D20, D21 & D22
    * Place the LEDs in thier designated places on the PCB folding them over then bending legs out to hold in place
    * Make sure to align the LEDs properly using the silk guide to place longest leg one position over from the square hole, folding the LEDs in the direction indicated to place the body of the LED over the solder mask void on the PCB
    * Solder all the LED connections
    * When cooled cut the component legs off at the top of the solder joints (do not cut into the solder joint)

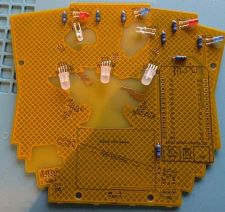
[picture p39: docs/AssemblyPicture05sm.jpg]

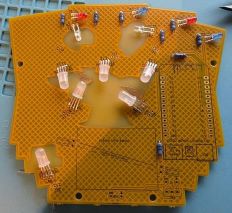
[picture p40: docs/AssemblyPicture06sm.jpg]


* Capacitors
  * The six capacitors are tan colored 2.5mm wide 2 pin 100nF non-polar ceramic disc capacitors (that look like Ibuprofen tablets) which are labeled C10-12, C20-22
  * Place all the capacitors in thier designated places on the PCB bending legs out to hold in place
  * These are non-polar so they can be placed in either direction.
  * Solder all the capacitor connections
  * The large ground plane makes one of the pins take a bit longer to heat up and the thin legs and larger pads make for uneven heating.  So, take a little more time to make sure these have a good connection.
  * When cooled cut the component legs off at the top of the solder joints (do not cut into the solder joint)

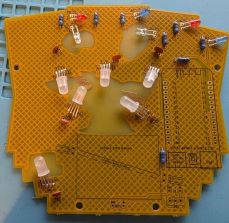
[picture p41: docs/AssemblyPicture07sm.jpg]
Capacitors


* Switch for battery power
  * The battery power switch is a 3-pin SPDT switch with a 5mm lever and right angle pins
  * Place the switch in its designated place on the PCB with the lever pointing towards the PCB edge. 
  * You might need to tilt it a bit to allow the pins to stick through the PCB enough to easily solder them.
  * Solder all the switch connections

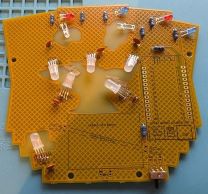
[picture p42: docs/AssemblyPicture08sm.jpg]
Switch


* Battery Holder Right Angle Male Headers
  * The 2.54mm 1x2 Pin Right Angle Male Headers are used with a rubber band to secure the lipo battery and are labeled J2 and J3 on the PCB
  * Place the short side of the header pins into the designated positions on the PCB with the long side pointing away from where the battery will be placed later.
  * Solder all the connections
  * It may be tricky to solder them while keeping them from pressing against the PCB, try soldering only one pin then adjust the header while applying heat to that pin

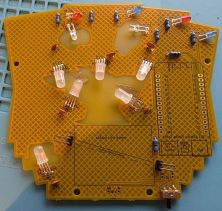
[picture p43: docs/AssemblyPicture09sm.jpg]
Battery_Holder


* The ESP32 development board
  * This is a 26 pin ESP32 WeMos Lolin32 development board with two 1x13 pin male header strips
  * You can either solder the male header pins to the ESP32 board first then solder that to the badge PCB or solder the male header pins to the badge PCB first then solder the ESP32 board to those pins
  * In either case we want to have the long ends of the male header pins pointing away from the badge PCB so that we do not need to cut those pins on the front of the badge.
  * Make sure to place the ESP32 in its designated place on the PCB and ensure it is aligned properly according to the silk drawing on the badge PCB (look at the USB and Battery connector symbols drawn in silkscreen)
  * Solder all the connections

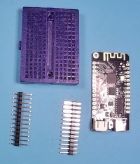
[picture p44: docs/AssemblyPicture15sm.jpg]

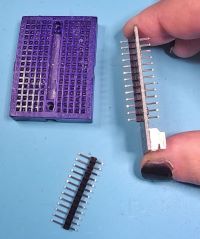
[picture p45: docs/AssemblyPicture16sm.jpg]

ESP32_dev_board
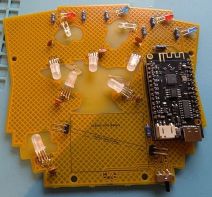
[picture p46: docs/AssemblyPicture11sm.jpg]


* ESP32 Battery Power Wires
  * The ESP32 development board has a JST mini PH battery power connector which needs to be connected to the badge PCB
  * The JST mini PH connector is keyed allowing it to only be plugged in one way
  * You can plug the connector into the ESP32 dev board to measure where to cut these wires to size, do not cut them too short or leave too much slack.
  * Disconnect the connector before attaching and soldering the wires.
  * WARNING: Unfourtunatley the JST mini PH Connector Wires that were available for this project had the red and black wires in the WRONG positions for this ESP32 dev board.
    * This means that the red wire which is usually an idication of Positive power is actually aligned with the Ground/Negative power terminal on the ESP32 dev board and visa versa for the black wire.
    * When connecting these wires to the badge PCB J1 pads you will need to connect the RED TO GND (round pad) and BLACK TO + (square pad)
    * Failure to do this will result in REVERSE POLARITY that will DESTROY the ESP32 dev board.
    * Reminder labels have been attached to these wires as a WARNING
  * Solder the connections
  * When cooled trim any excess wire at the top of the solder joints (do not cut into the solder joint)
  * Verify that the connector can reach to be plugged into the ESP43 dev board (you might need to twist the connector around to line it up)
  * Be sure to disconnect this connector since we do not want it connected when working with the LIPO Battery

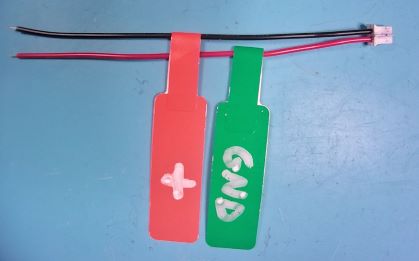
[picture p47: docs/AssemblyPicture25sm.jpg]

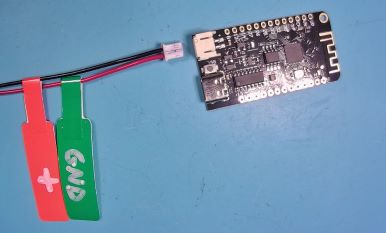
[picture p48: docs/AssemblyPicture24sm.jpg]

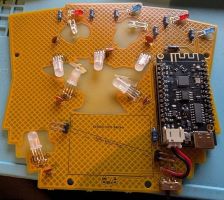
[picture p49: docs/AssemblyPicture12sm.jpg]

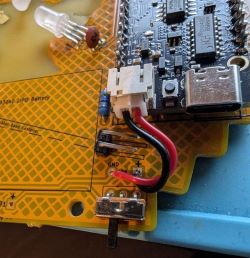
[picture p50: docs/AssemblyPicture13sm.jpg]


* LIPO Battery
  * The LIPO Battery has a charge so you need to be careful when working with it
    * Make sure not to touch the battery wires together by only stripping and soldering one wire at a time
    * Make sure battery power will not be applied to the badge by ensuring the ESP32 battery connector is disconnected and the badge switch is in the off position (towards the center of the badge)
  * Strip the tip of the BLACK battery wire and insert it into BT1 on the badge PCB in GND (round pad)
  * Solder this wire to the PCB
  * Strip the tip of the RED battery wire and insert it into BT1 on the badge PCB in + (square pad)
  * Solder this wire to the PCB
  * Place the battery onto the PCB within the designated square drawn in silk on the PCB
  * Attach a rubber band over the battery between the male header pins in J2 and J3
  * Plug in the ESP32 battery connector

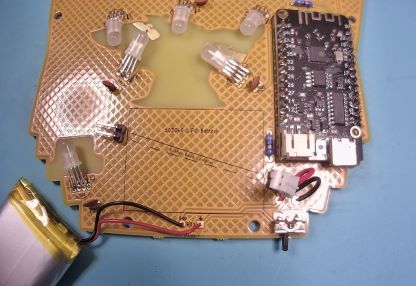
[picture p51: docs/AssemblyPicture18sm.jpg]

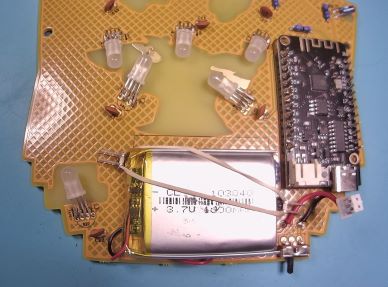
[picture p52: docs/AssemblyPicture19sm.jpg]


* Testing
  * Turn on the badge and make sure all the LEDs light up
  * If any of them do not then turn the badge off, make any necessary corrections and try again.
  * Turn the badge off when done before connecting the two PCBs

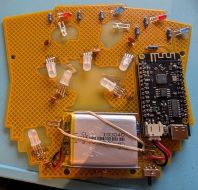
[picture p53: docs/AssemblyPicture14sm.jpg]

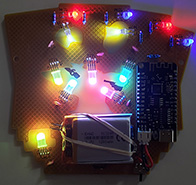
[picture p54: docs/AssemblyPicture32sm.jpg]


* Connect Both PCBs using Standoffs and M3 Screws
  * On the rear badge PCB (the one with no components) attach a brass 10mm standoff using a brass M3 screw in each of the four drill holes in that PCB making them reasonably tight (over tightening might crack the PCB)
  * Align the front and rear PCBs and on the front PCB insert the brass screws into the PCB and standoff connecting the two PCBs, but keep them only loosly connected at first
  * Check that the battery wires are fully clear of the standoffs as you tighten each of the four M3 screws on the front PCB making them reasonably tight (over tightening might crack the PCB)

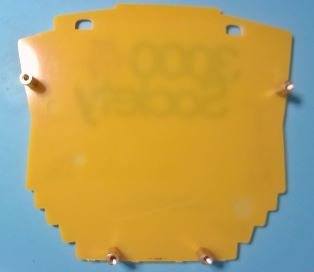
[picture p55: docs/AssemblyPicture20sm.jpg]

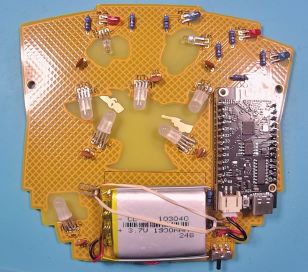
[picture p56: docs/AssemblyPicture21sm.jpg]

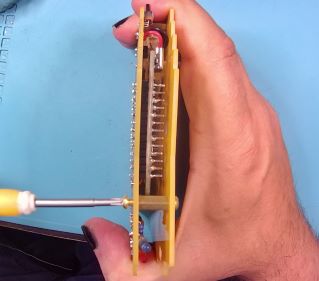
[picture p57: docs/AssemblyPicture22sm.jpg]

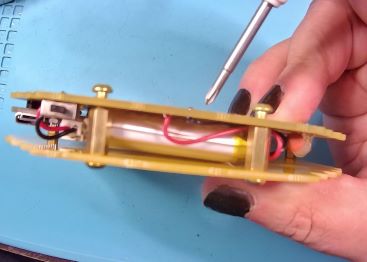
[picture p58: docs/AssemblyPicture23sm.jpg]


* Enjoy!
  * Attach the lanyard and enjoy your new creation.

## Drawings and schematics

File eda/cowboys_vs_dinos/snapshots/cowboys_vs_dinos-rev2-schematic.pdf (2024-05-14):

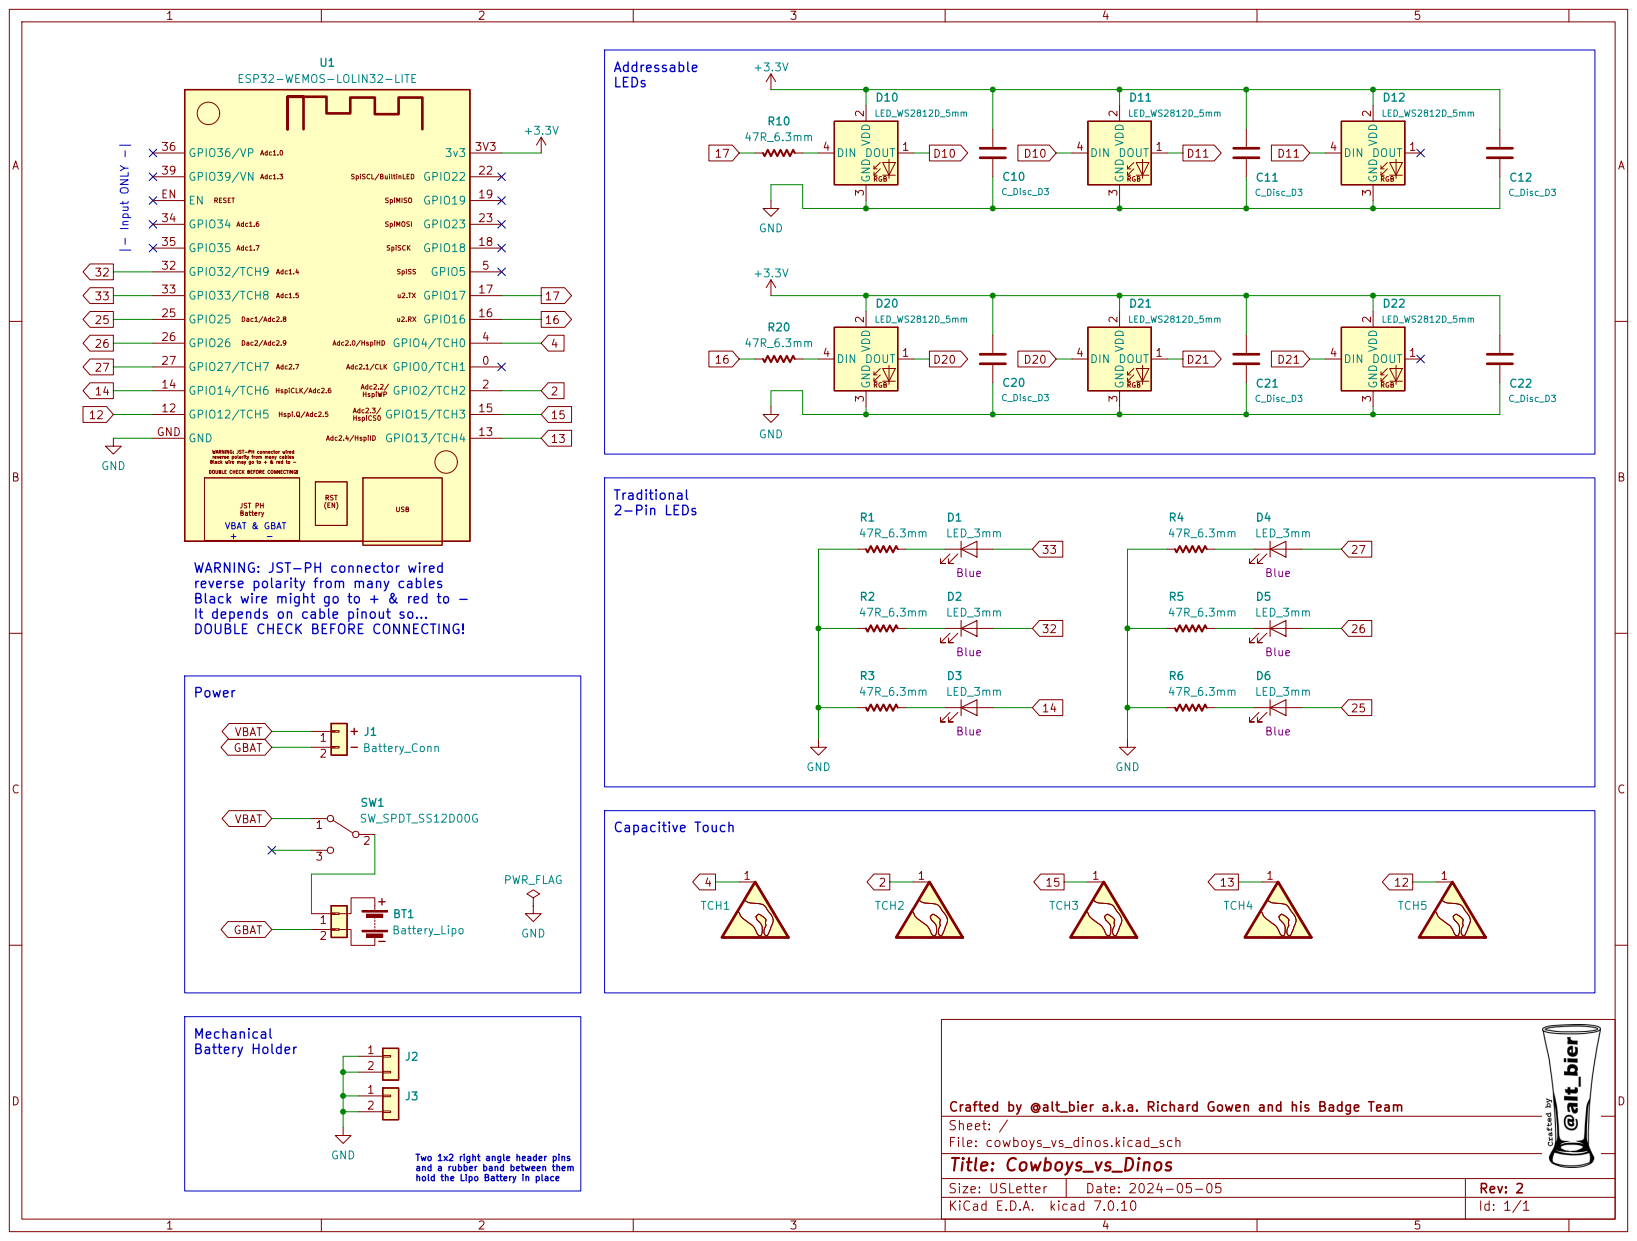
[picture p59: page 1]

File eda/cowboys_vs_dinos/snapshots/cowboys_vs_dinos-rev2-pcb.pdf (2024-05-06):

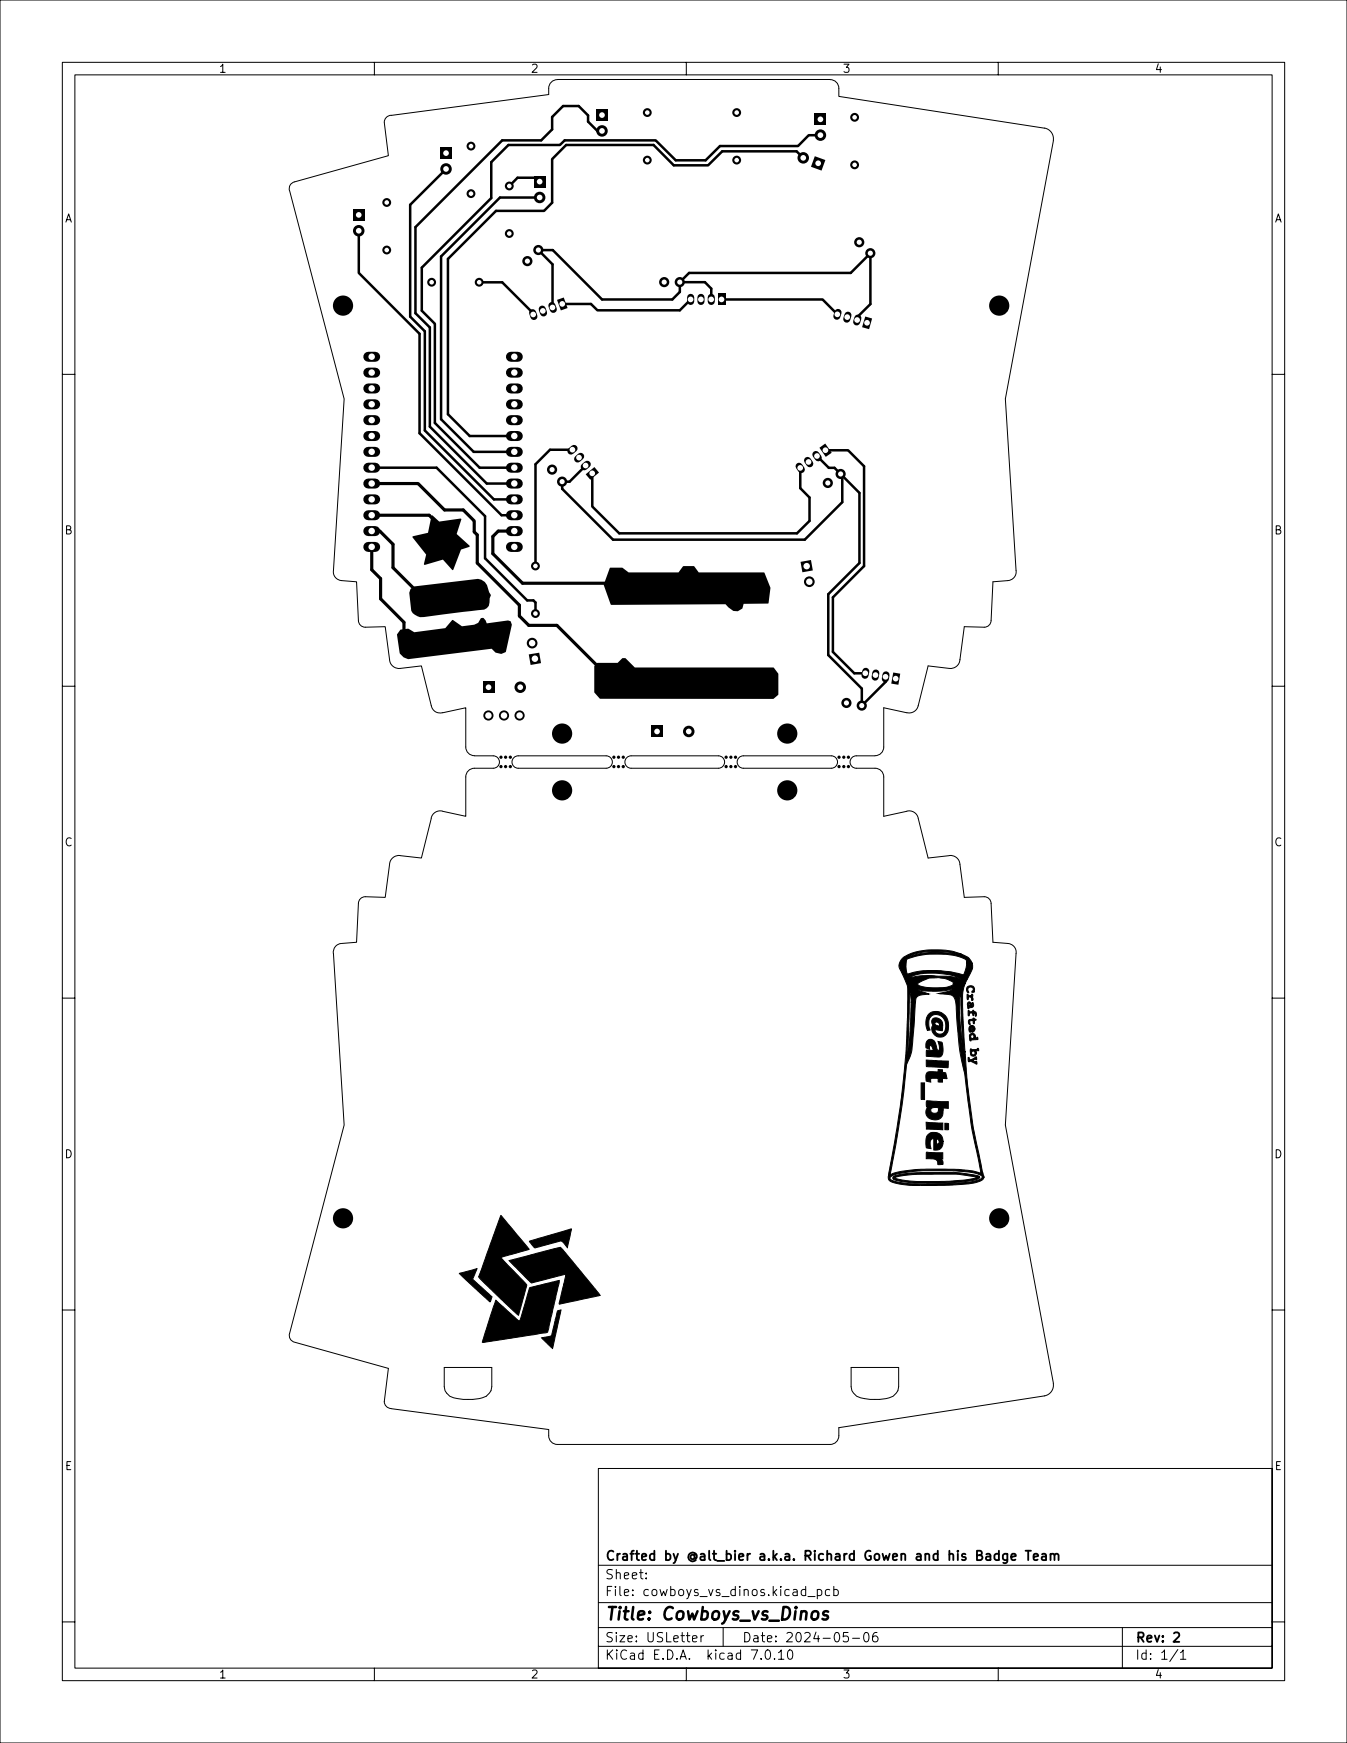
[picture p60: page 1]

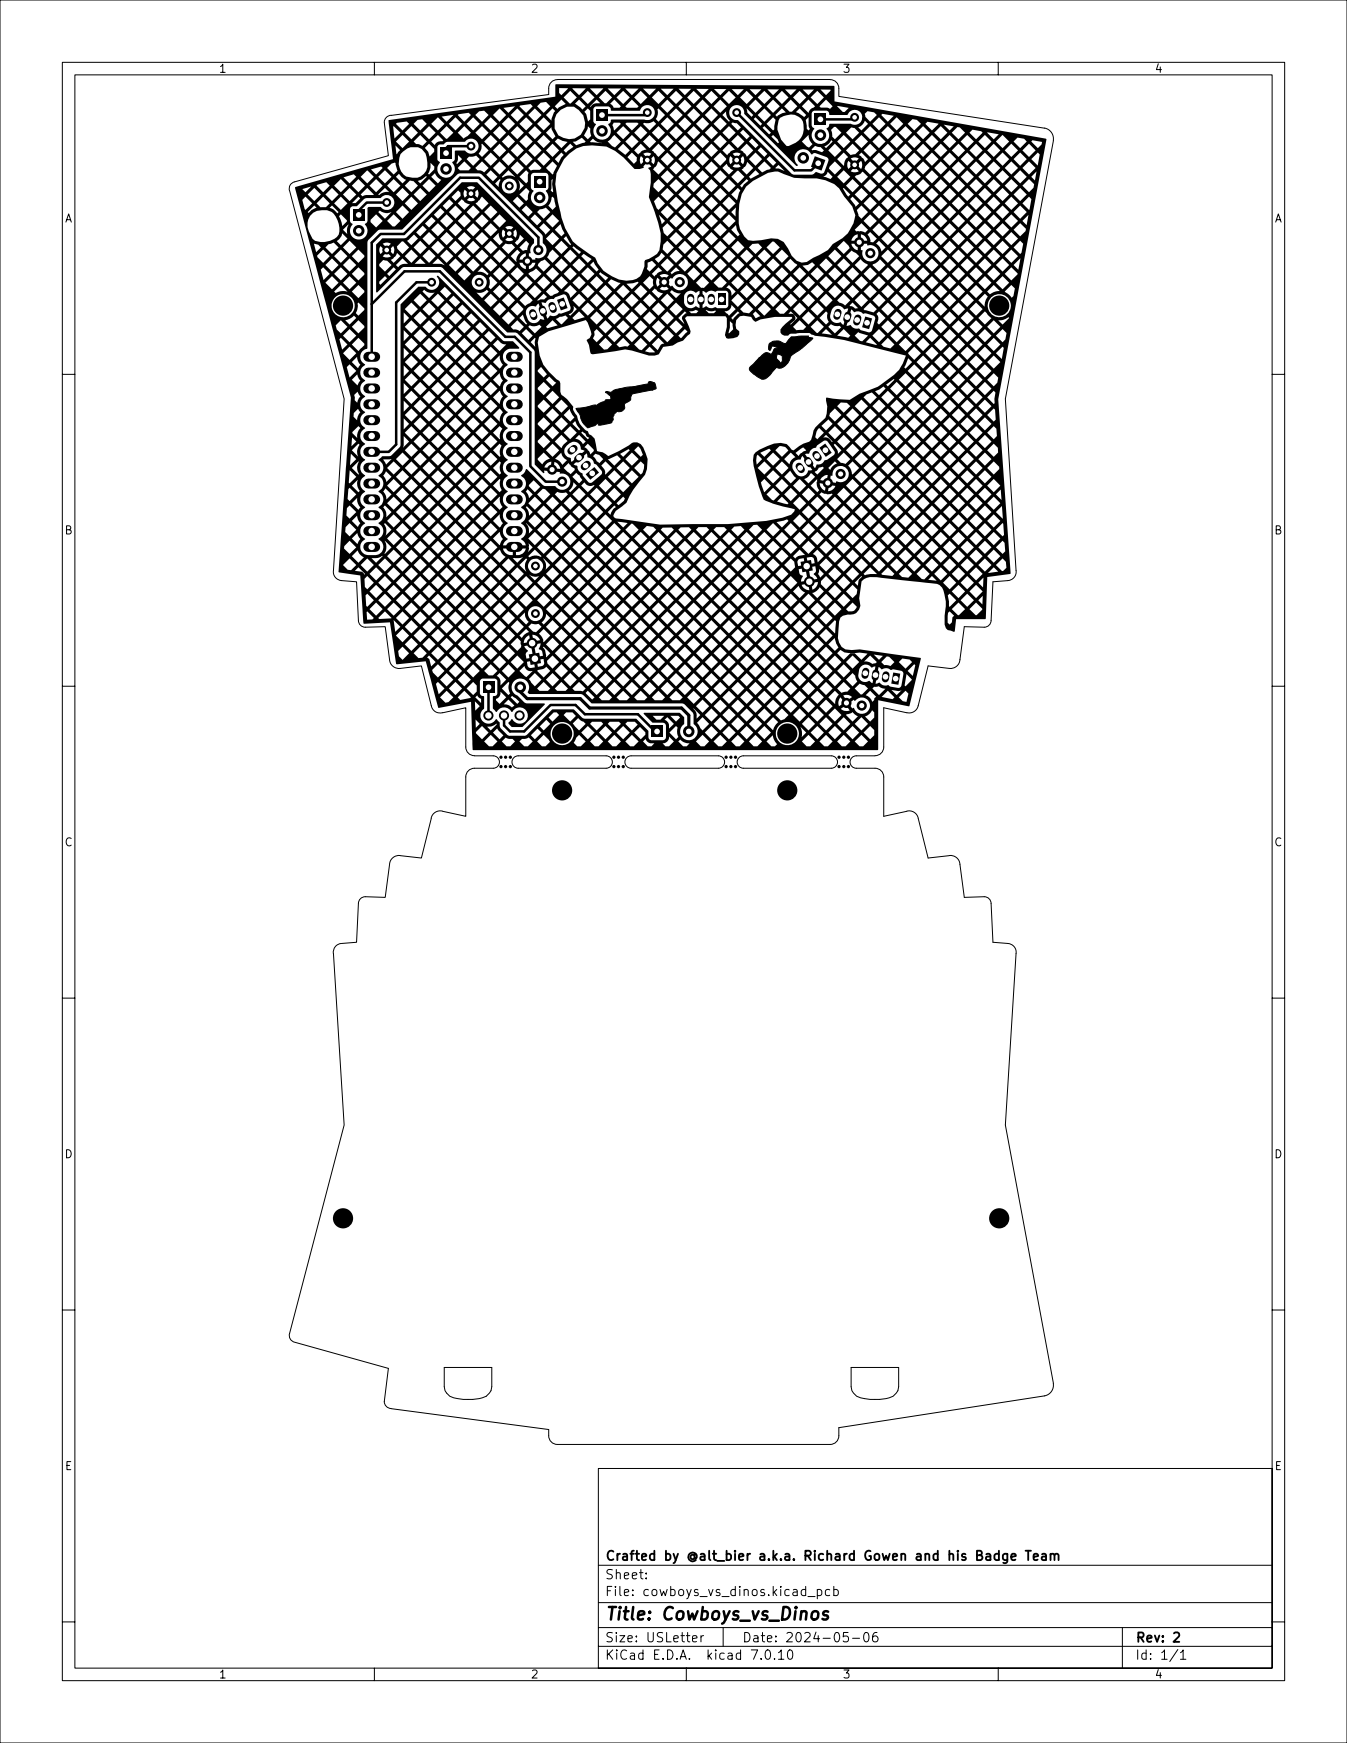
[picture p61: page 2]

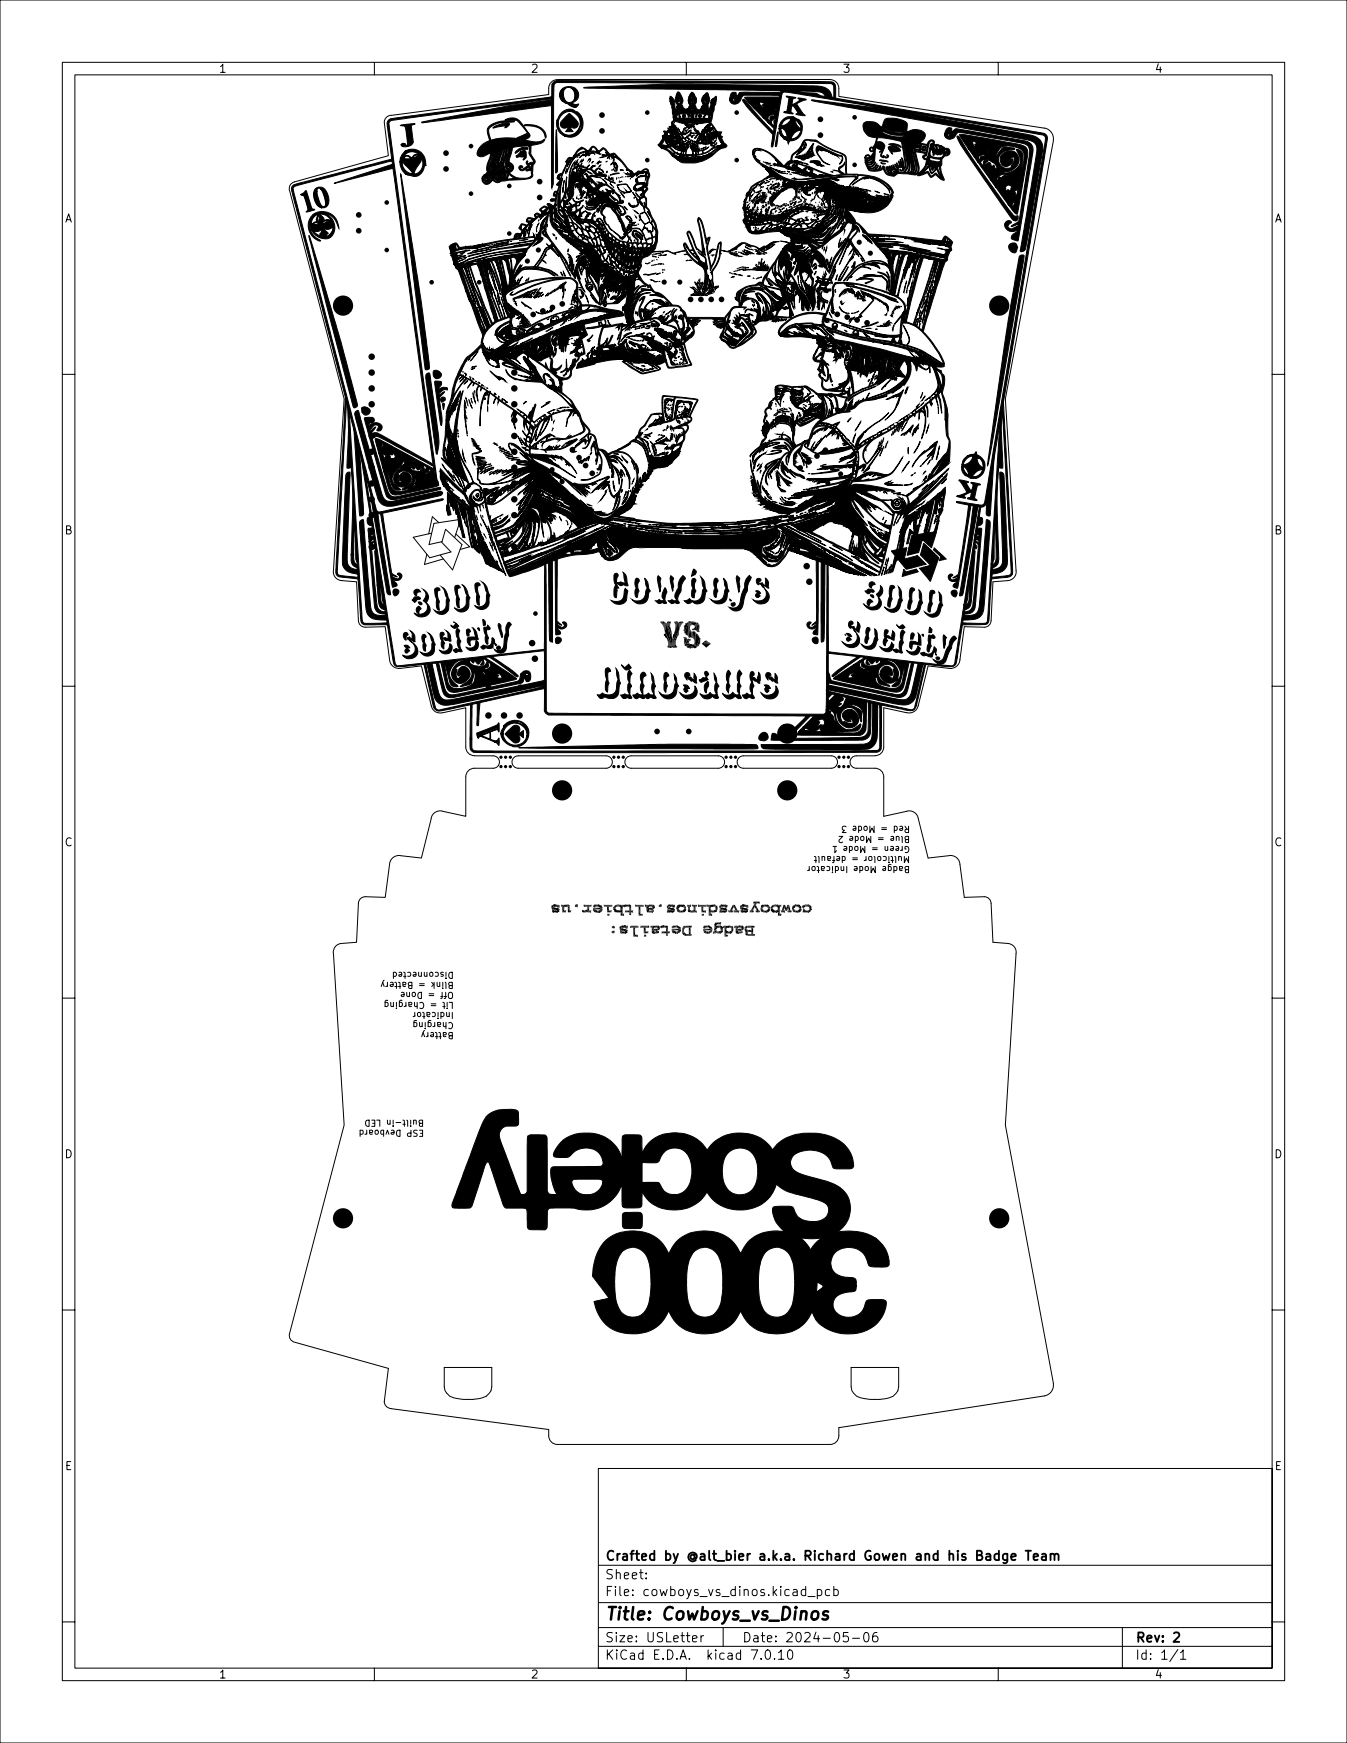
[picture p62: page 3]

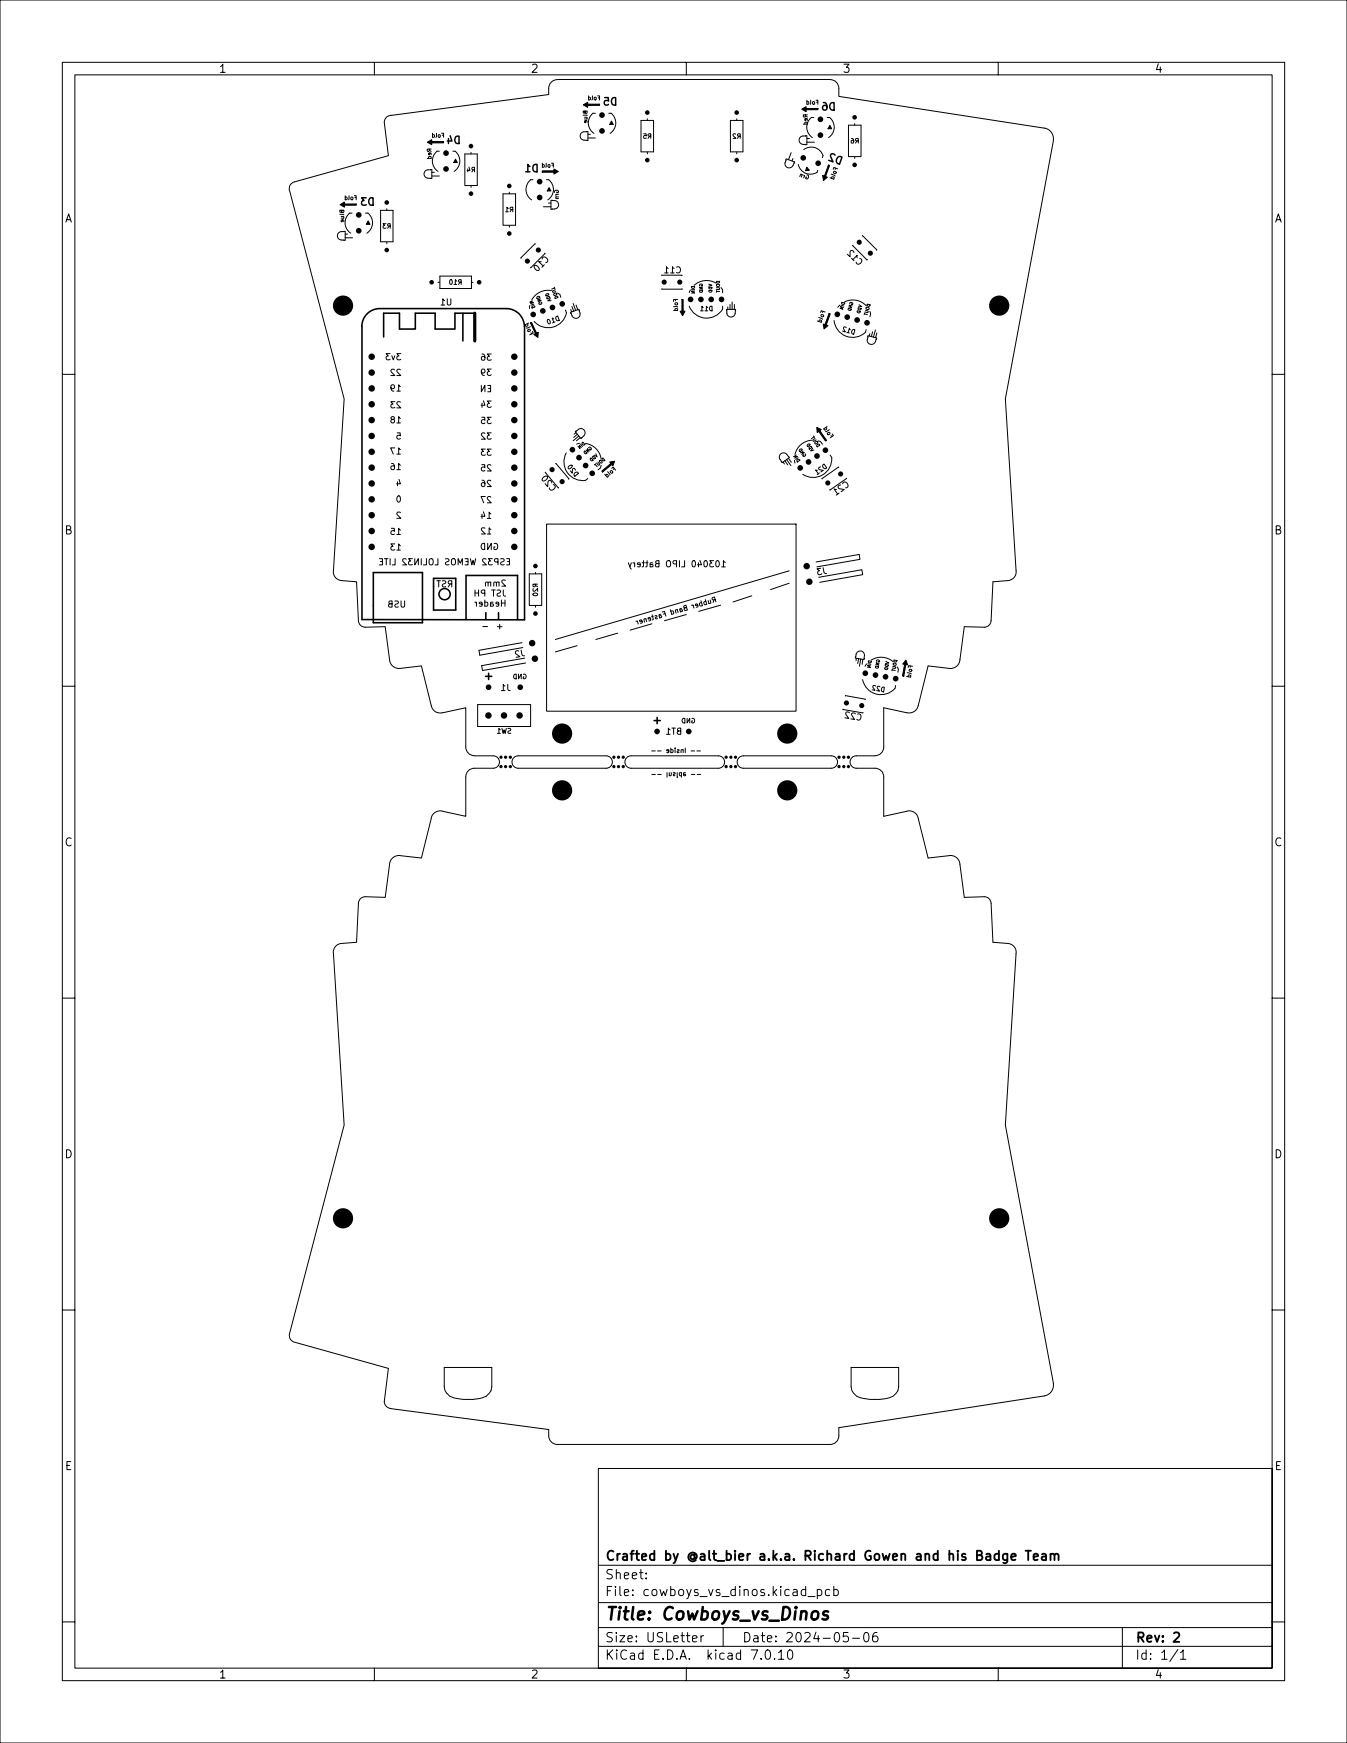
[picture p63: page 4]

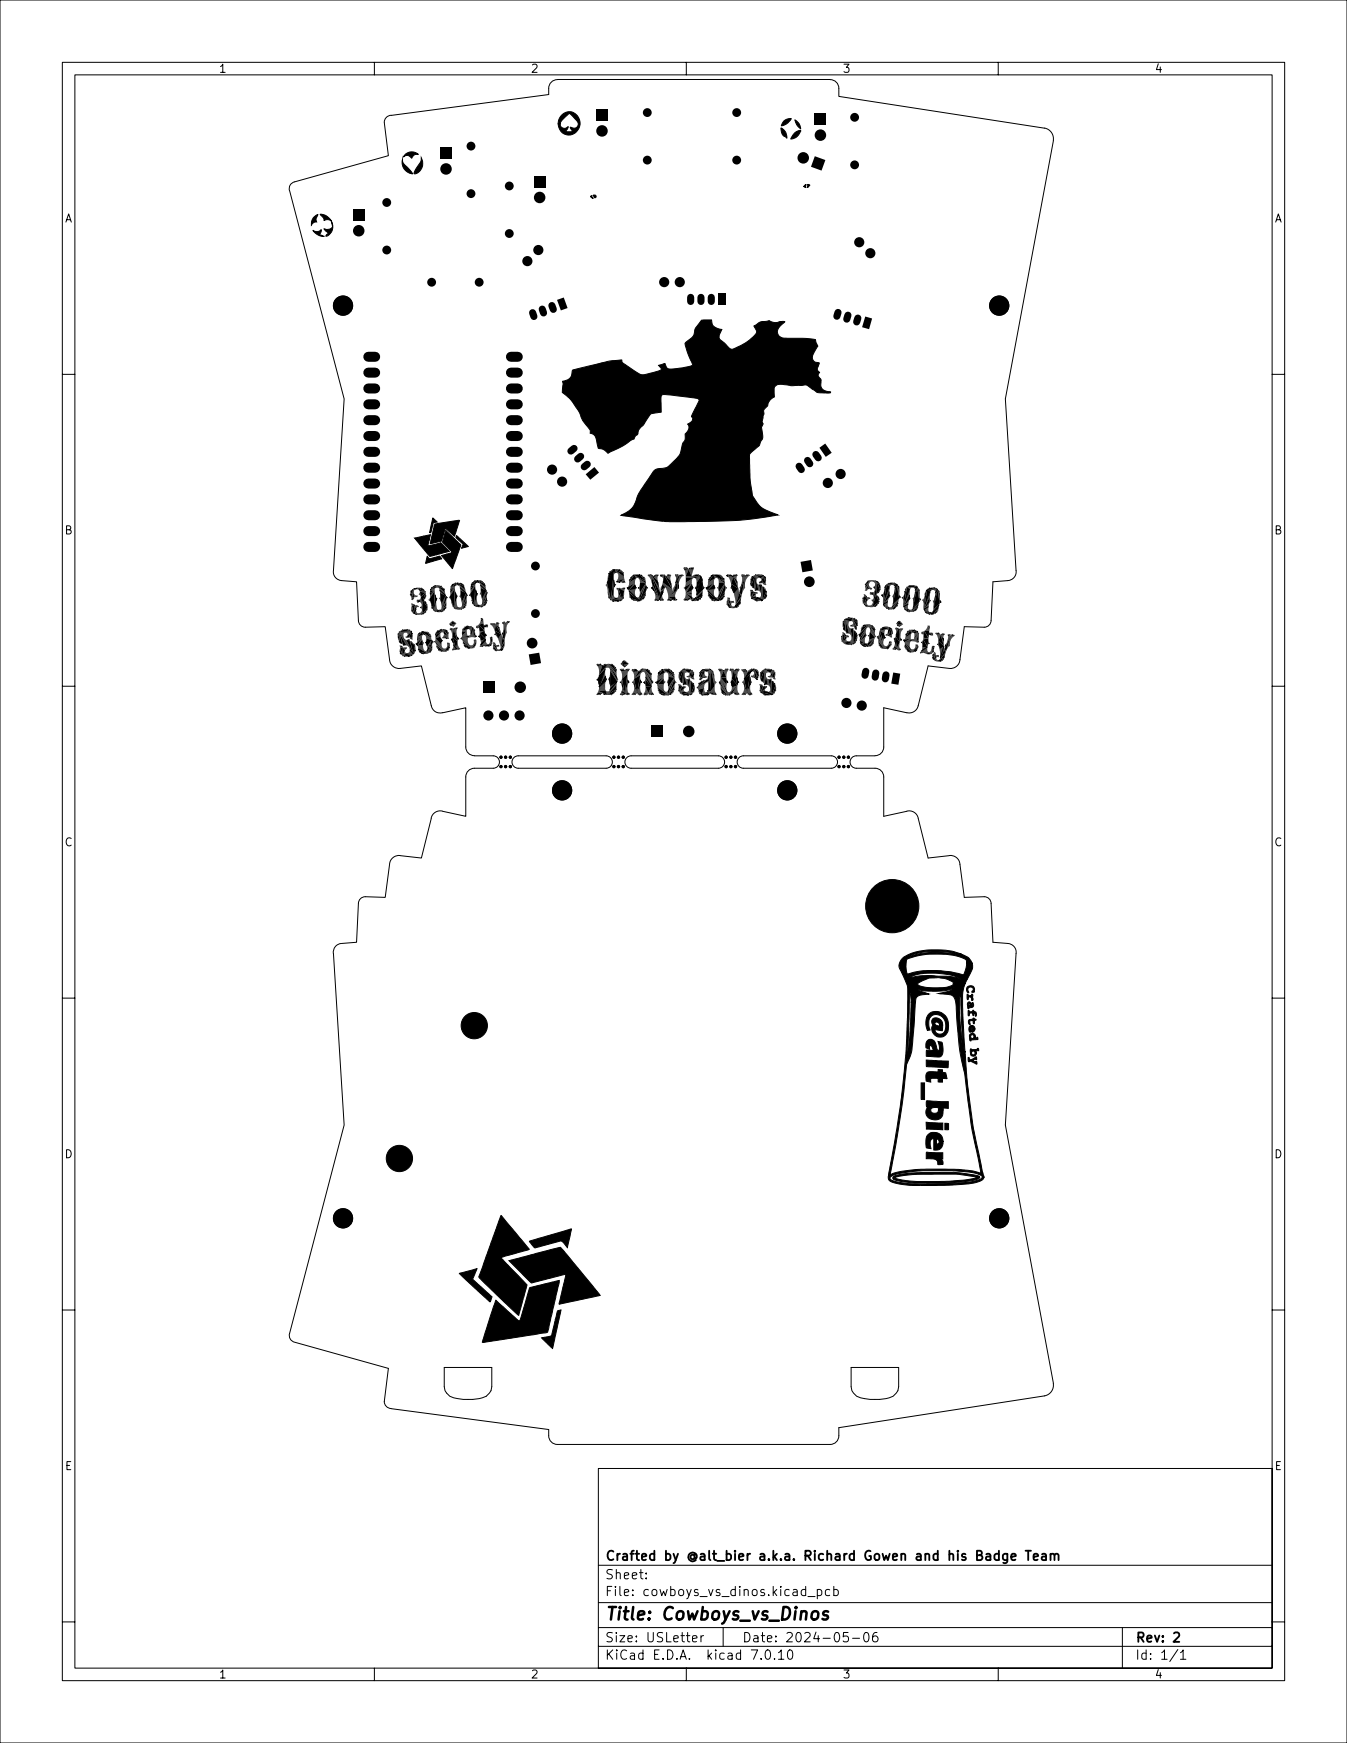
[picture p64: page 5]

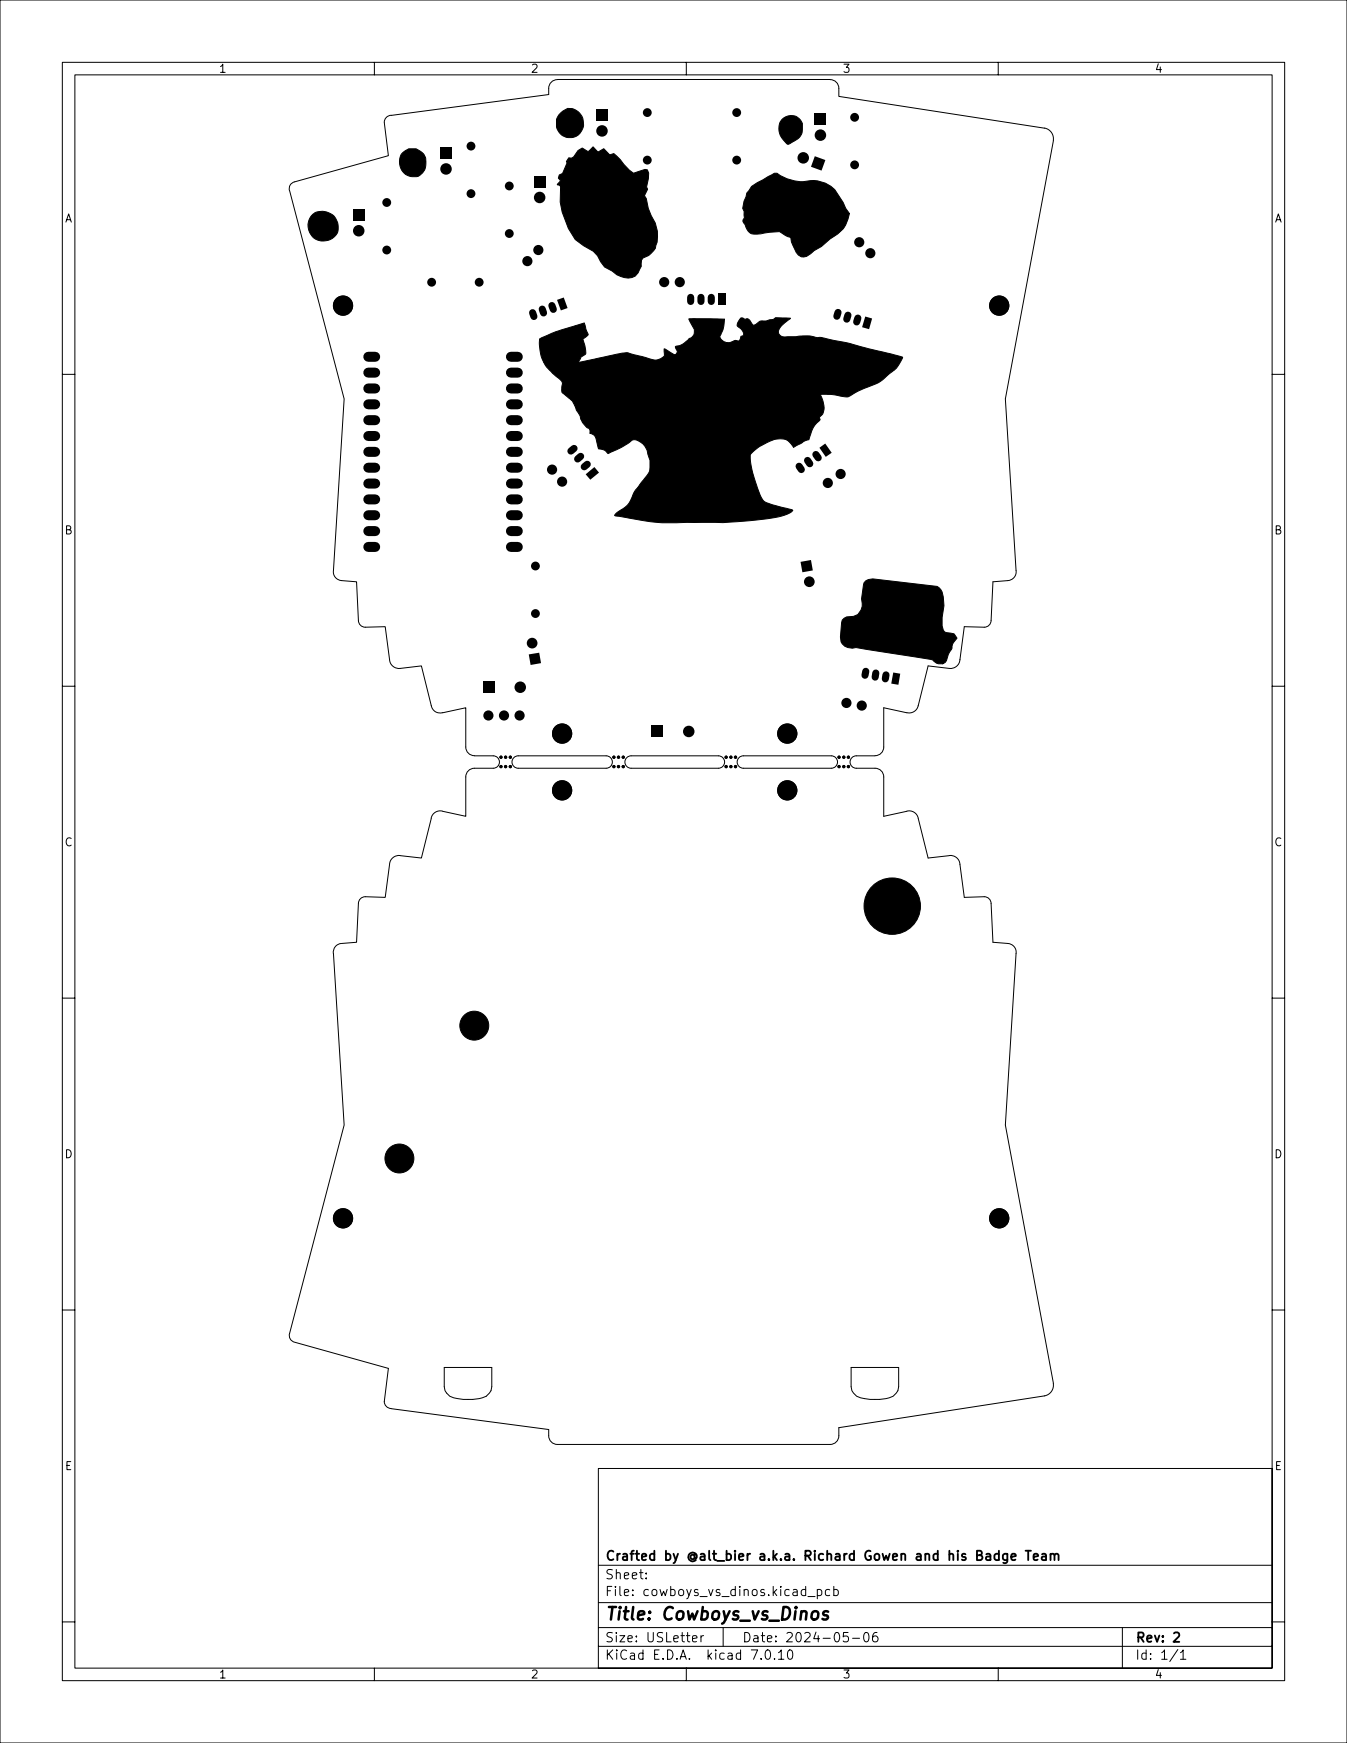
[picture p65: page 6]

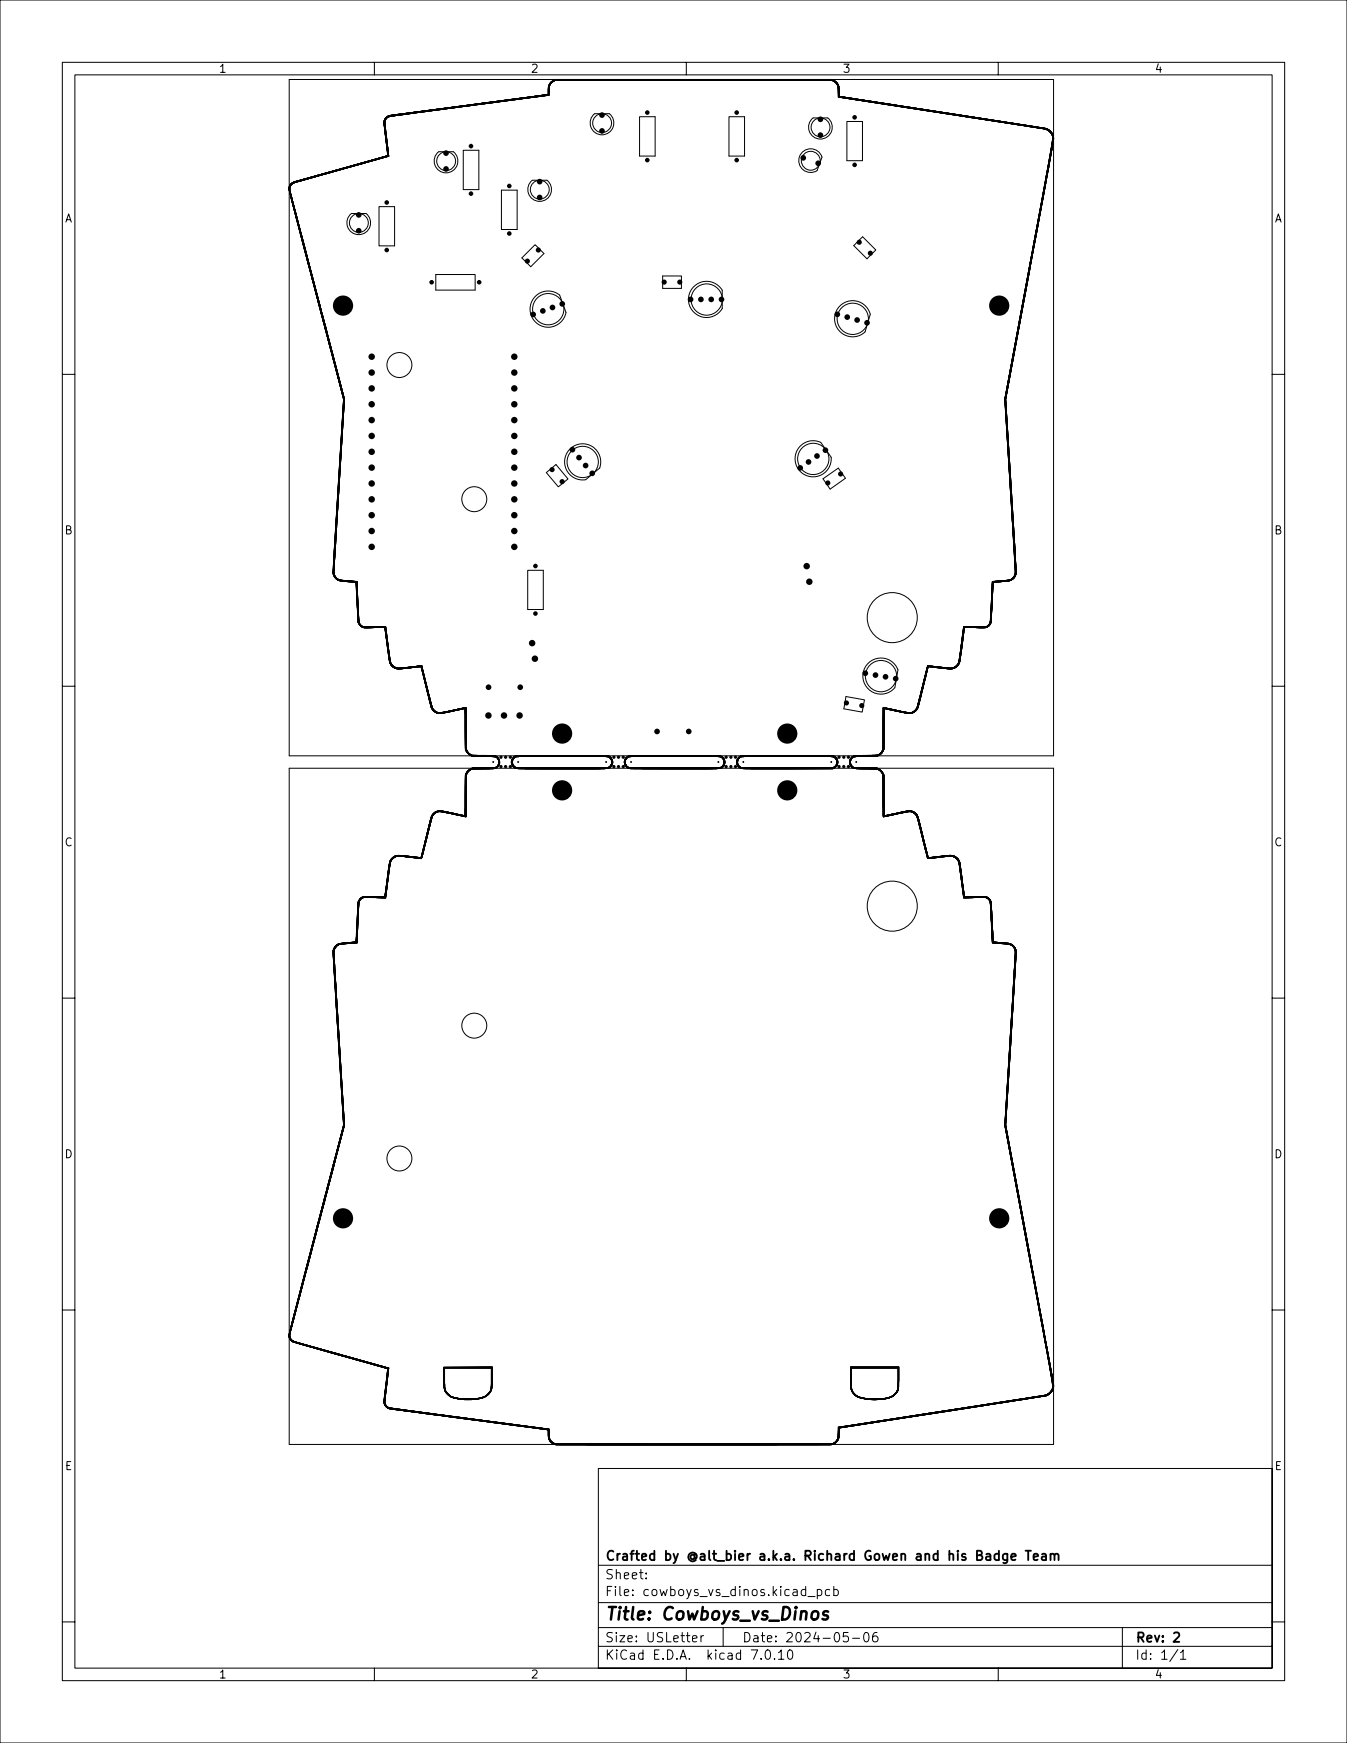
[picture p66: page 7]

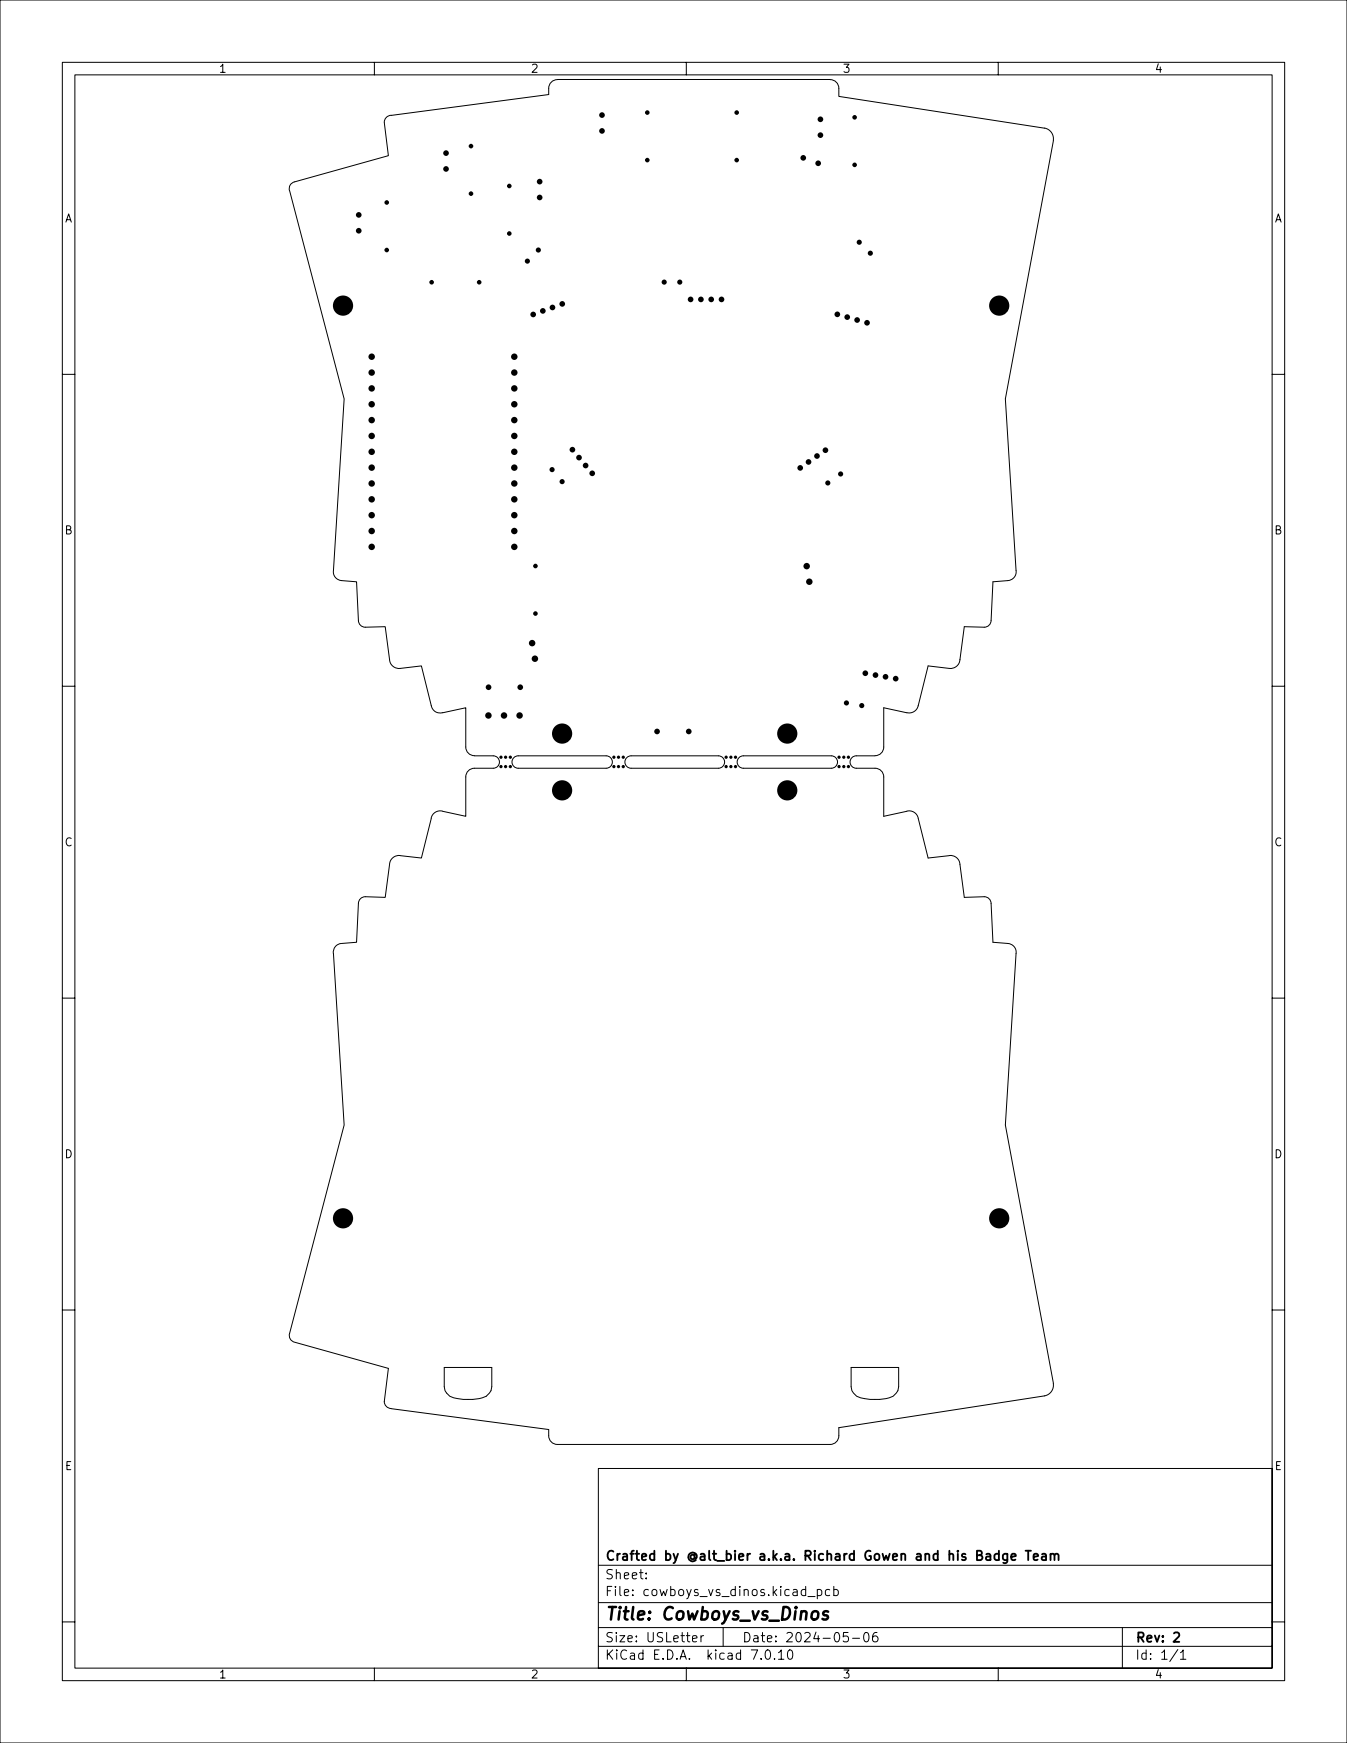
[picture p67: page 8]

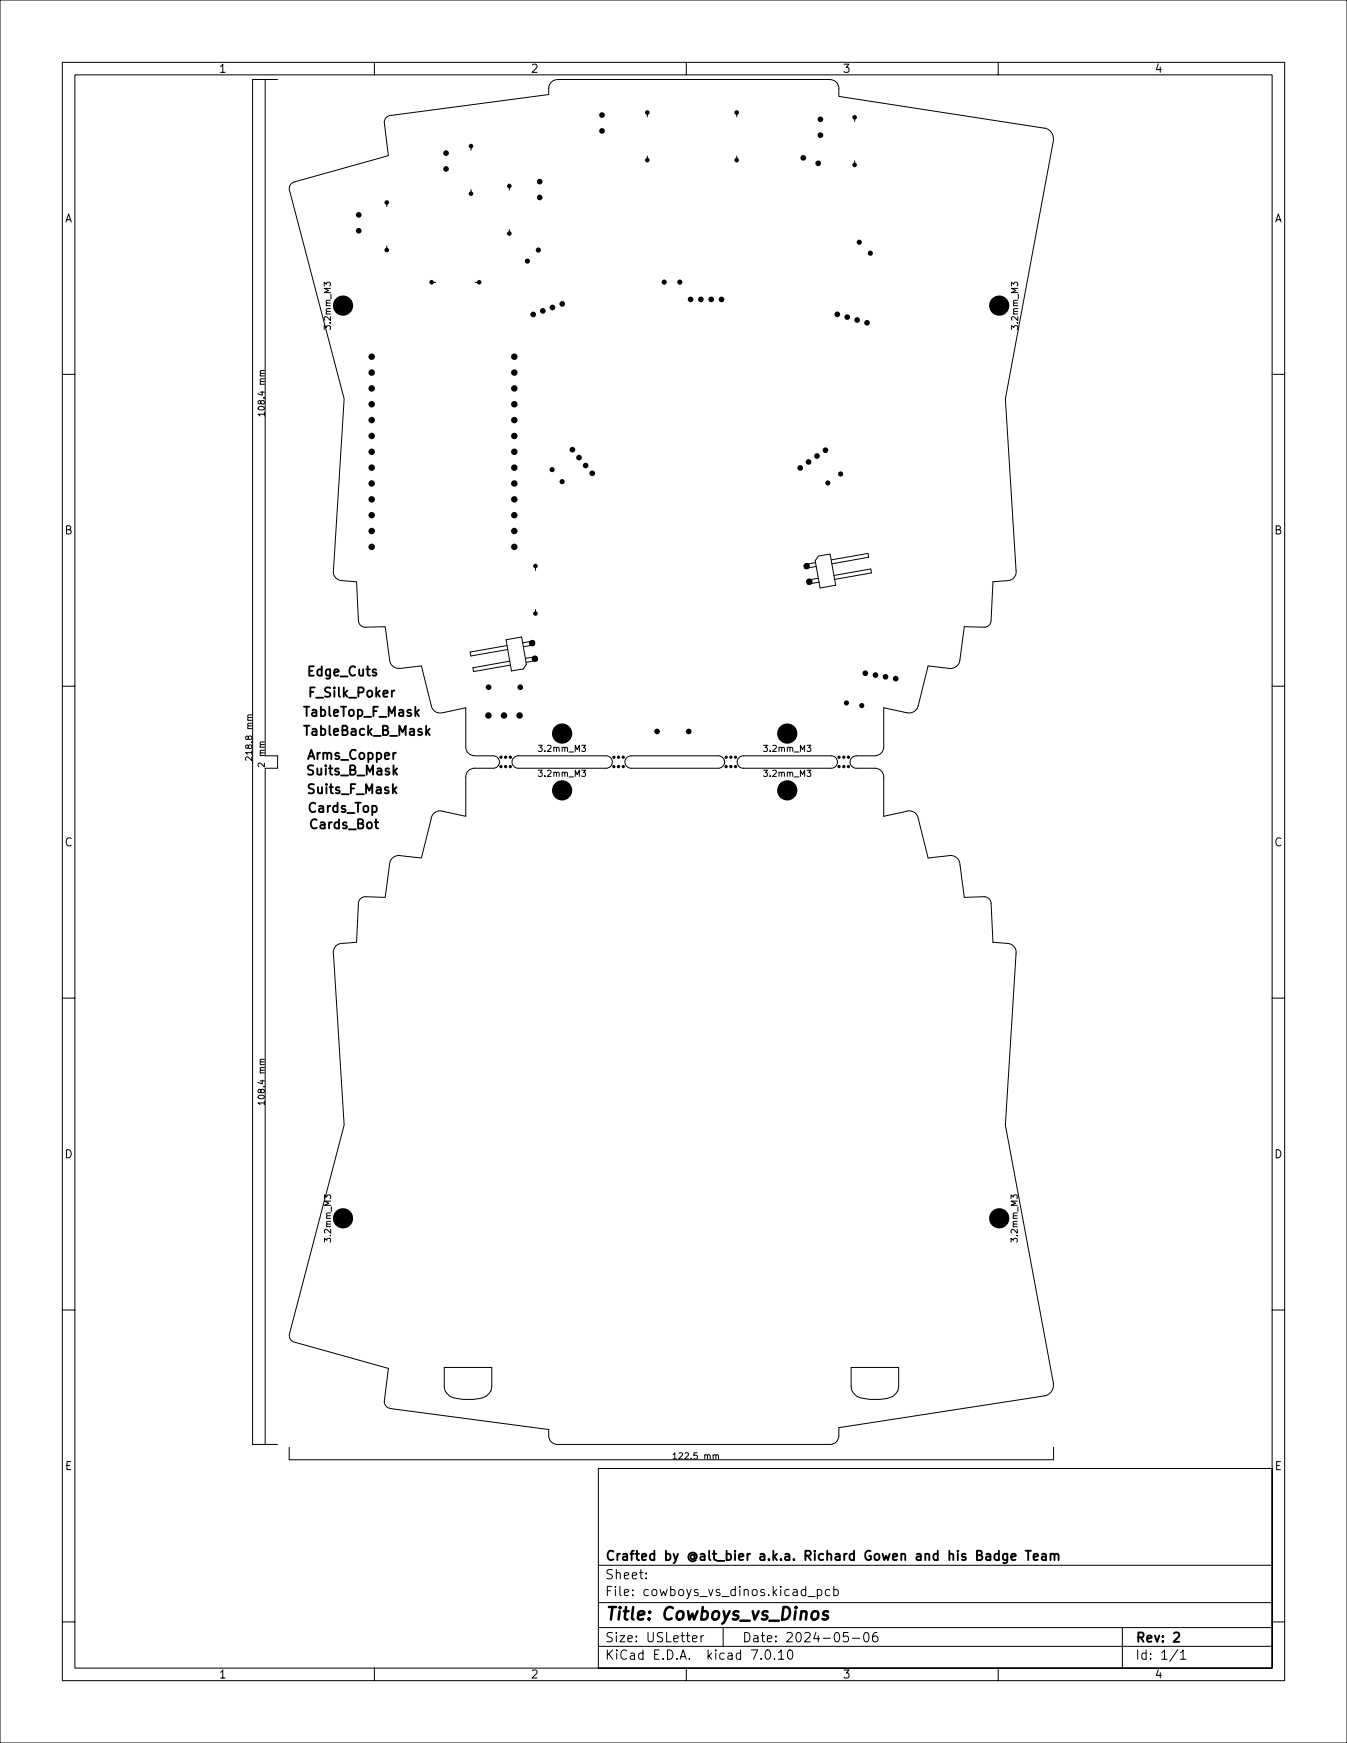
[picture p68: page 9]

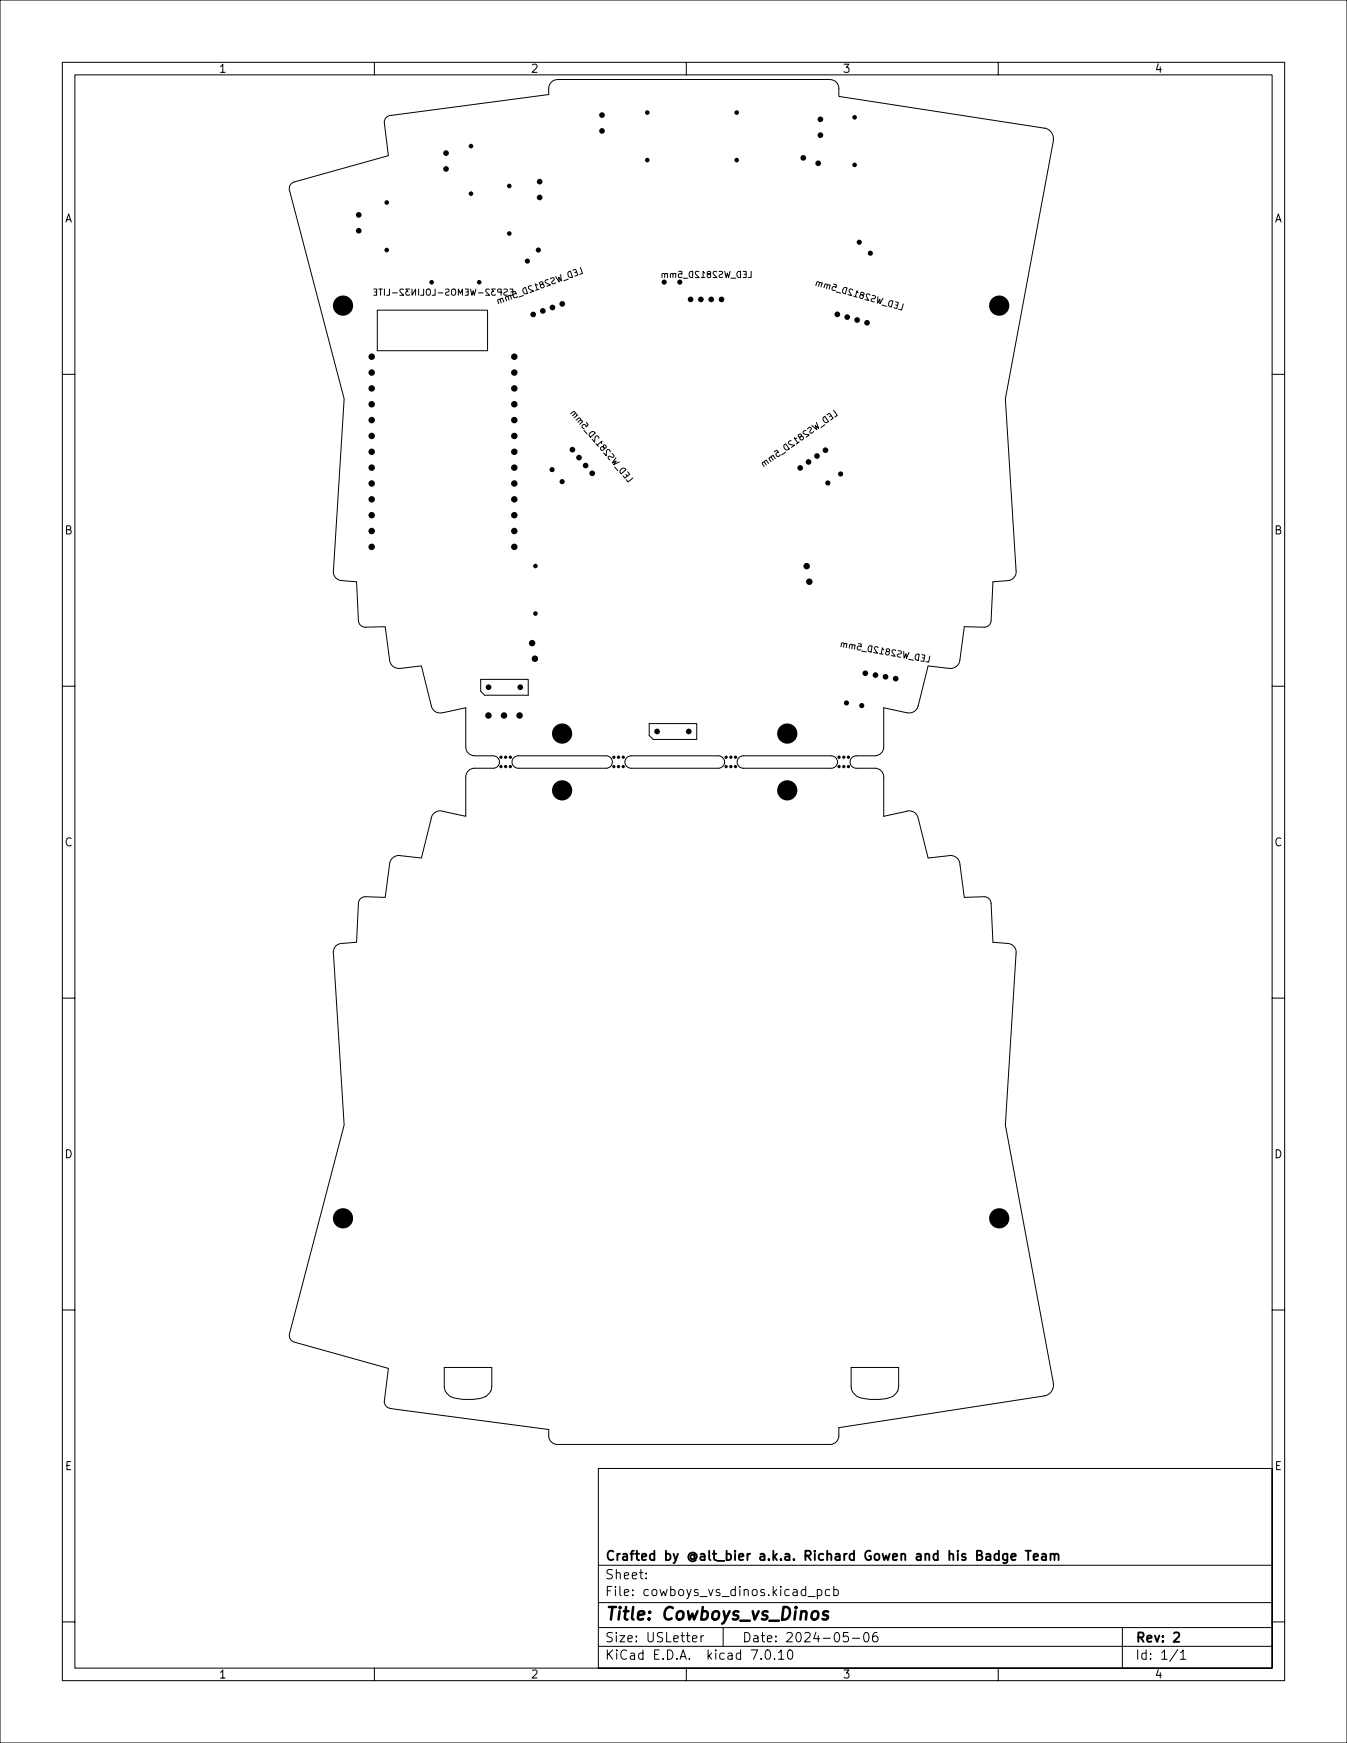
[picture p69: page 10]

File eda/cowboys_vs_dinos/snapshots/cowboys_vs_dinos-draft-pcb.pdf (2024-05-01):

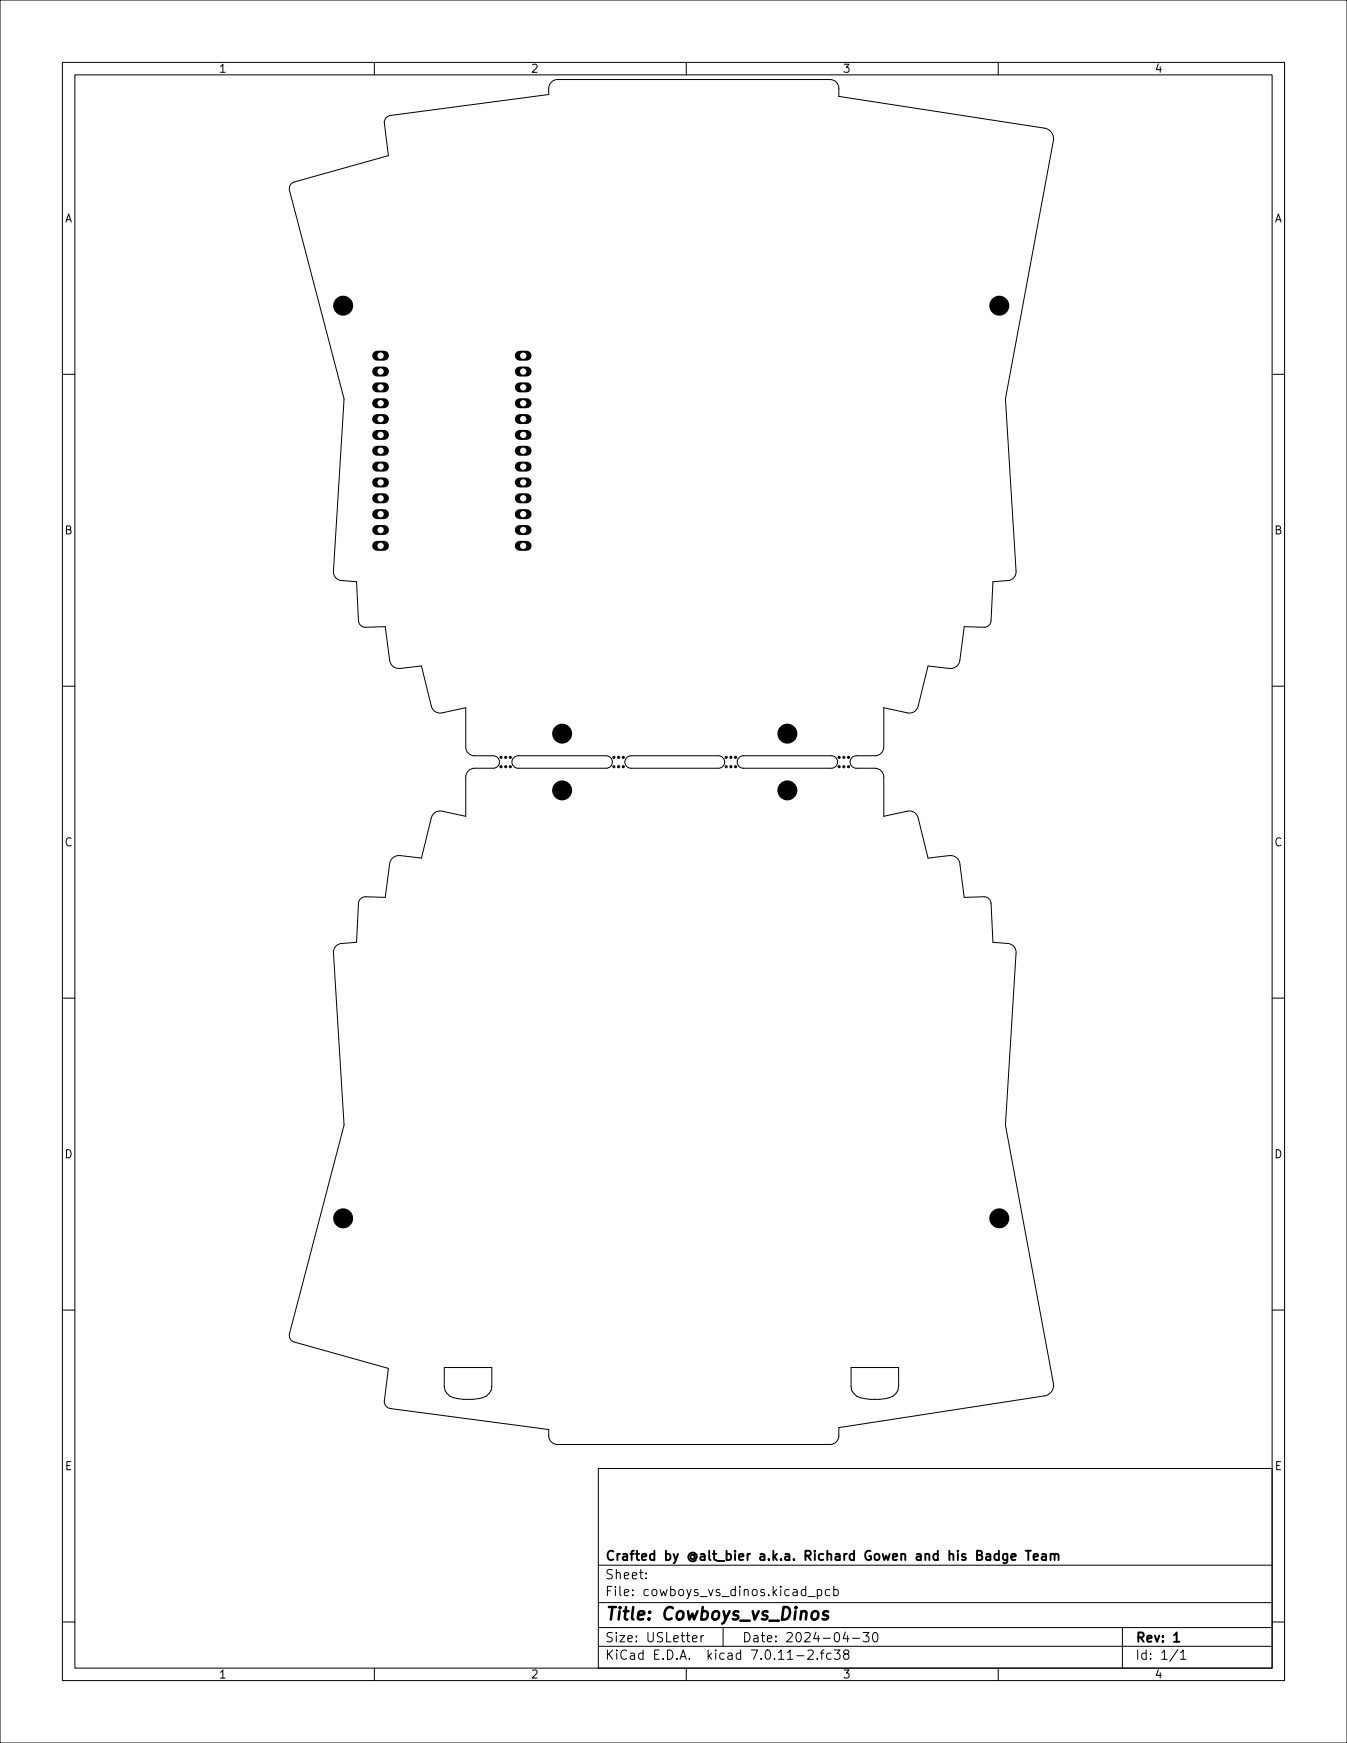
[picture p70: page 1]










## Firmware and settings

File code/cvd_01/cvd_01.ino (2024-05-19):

// cowbooys vs dinosaurs badge code rev01

// Include Libraries
#include <Arduino.h>
#include <WiFi.h>
#include "Adafruit_NeoPixel.h"
#include "SPI.h"
#include <driver/adc.h>

// Pin Definitions
//
// NeoPixel Data Pins
#define NEO01_DATA 17
#define NEO02_DATA 16
//
// One color LED Pins
#define LED_D1 33  // White - Left Dino no hat
#define LED_D2 32  // White - Right Dino hat
#define LED_D3 14  // Blue - Clubs 10
#define LED_D4 27  // Red - Hearts J
#define LED_D5 26  // Blue - Spades Q
#define LED_D6 25  // Red - Diamonds K
//
// Built-in LED
#define LED_BI 22

//
// Capacitive Touch Pins
#define TCH01_PIN 4  // Dinosaurs
#define TCH02_PIN 2  // Logo
#define TCH03_PIN 15 // 3000
#define TCH04_PIN 13 // Society
#define TCH05_PIN 12 // Cowboys

// NeoPixel Properties
//
// Define NeoPixel Strips - (Num pixels, pin to send signals, pixel type, signal rate)
Adafruit_NeoPixel NEO01 = Adafruit_NeoPixel(3, NEO01_DATA, NEO_RGB + NEO_KHZ800);
Adafruit_NeoPixel NEO02 = Adafruit_NeoPixel(3, NEO02_DATA, NEO_RGB + NEO_KHZ800);
// Status NeoPixel LED color mode default=0 green=1 blue=2 red=3
int status_neo_mode = 0;

// PWM Properties
//
// Signal Frequency in Hz
const int freq = 1000;
// Duty Cycle Resolution in bits (1-16)
const int resolution = 8;
// PWM channel Assignment (0-15)
const int LED_D1_pwm = 1;
const int LED_D2_pwm = 2;
const int LED_D3_pwm = 3;
const int LED_D4_pwm = 4;
const int LED_D5_pwm = 5;
const int LED_D6_pwm = 6;

// Wireless Properties
//
// WIFI status codes
const char* wl_status_to_string(wl_status_t status) {
  switch (status) {
    case WL_NO_SHIELD: return "WL_NO_SHIELD";
    case WL_IDLE_STATUS: return "WL_IDLE_STATUS";
    case WL_NO_SSID_AVAIL: return "WL_NO_SSID_AVAIL";
    case WL_SCAN_COMPLETED: return "WL_SCAN_COMPLETED";
    case WL_CONNECTED: return "WL_CONNECTED";
    case WL_CONNECT_FAILED: return "WL_CONNECT_FAILED";
    case WL_CONNECTION_LOST: return "WL_CONNECTION_LOST";
    case WL_DISCONNECTED: return "WL_DISCONNECTED";
  }
}

// Capacitive Touch Properties
//
// Touch Thresholds
int Touch01_Threshold = 19;
int Touch02_Threshold = 19;
int Touch03_Threshold = 19;
int Touch04_Threshold = 19;
int Touch05_Threshold = 19;
// Touch Initial Values
int Touch01_Value = 21;
int Touch02_Value = 21;
int Touch03_Value = 21;
int Touch04_Value = 21;
int Touch05_Value = 21;
//
// Touch Counters
//
// Touch Iteration Counter
int Touch01_IntCount = 0;
int Touch02_IntCount = 0;
int Touch03_IntCount = 0;
int Touch04_IntCount = 0;
int Touch05_IntCount = 0;
// Touch Loop Counter
int Touch01_LoopCount = 0;
int Touch02_LoopCount = 0;
int Touch03_LoopCount = 0;
int Touch04_LoopCount = 0;
int Touch05_LoopCount = 0;
// Touch Loop Threshold (Touch Held for X Loops of Main)
int Touch01_Loop_Threshold = 3;
int Touch02_Loop_Threshold = 3;
int Touch03_Loop_Threshold = 3;
int Touch04_Loop_Threshold = 3;
int Touch05_Loop_Threshold = 3;

// Loop Control Properties
//
// Main Loop LED Iteration Delay Time [in ms]
int LEDDelayTime = 15;
//
// Debug Serial - If set greater than 0 it writes to serial for debugging
// 0 = no debug text
// 1 = basic debug info once per main loop
// 2 = extra debug info
int DebugSerial = 2;

// //////////////////////////////////////////////////
//
// SETUP - RUN ONCE
//
// //////////////////////////////////////////////////
void setup(){
  // Add a delay to allow opening serial monitor
  delay(800);

  // setup the serial output baud rate
  Serial.begin(115200);

  if (DebugSerial >= 1) {
    Serial.println("Starting Setup");
  }

  // Turn Off WiFi/BT
  if (DebugSerial >= 2) {
    Serial.println("Turn Off WiFi / BlueTooth");
  }
  setModemSleep();

  // Configure LED PWM functionalitites per channel
  if (DebugSerial >= 2) {
    Serial.println("Configure PWM Channels");
  }
  ledcSetup(LED_D1_pwm, freq, resolution);
  ledcSetup(LED_D2_pwm, freq, resolution);
  ledcSetup(LED_D3_pwm, freq, resolution);
  ledcSetup(LED_D4_pwm, freq, resolution);
  ledcSetup(LED_D5_pwm, freq, resolution);
  ledcSetup(LED_D6_pwm, freq, resolution);

  // Attach the channel to the GPIO to be controlled
  if (DebugSerial >= 2) {
    Serial.println("Attach PWM Channels to LED Pins");
  }
  ledcAttachPin(LED_D1, LED_D1_pwm);
  ledcAttachPin(LED_D2, LED_D2_pwm);
  ledcAttachPin(LED_D3, LED_D3_pwm);
  ledcAttachPin(LED_D4, LED_D4_pwm);
  ledcAttachPin(LED_D5, LED_D5_pwm);
  ledcAttachPin(LED_D6, LED_D6_pwm);

  //Normal LED output
  if (DebugSerial >= 2) {
    Serial.println("Set Output for non-PWM LED Pins");
  }
  pinMode(LED_BI, OUTPUT);

  // Initialize the NeoPixels
  if (DebugSerial >= 2) {
    Serial.println("Initialize NeoPixels");
  }
  NEO01.begin();
  NEO02.begin(); 
  // Set Neopixel Brightness (0-255 scale)
  NEO01.setBrightness(170);
  NEO02.setBrightness(170);

  // Start all LEDs in OFF mode
  if (DebugSerial >= 2) {
    Serial.println("Turn OFF all LEDs");
  }
  ledAllOff();

  if (DebugSerial >= 1) {
    Serial.println(F("Setup Done!"));
  }

  // END OF SETUP
}

// //////////////////////////////////////////////////
//
// LOOP - MAIN 
//
// //////////////////////////////////////////////////
void loop(){
  if (DebugSerial >= 1) {
    Serial.println("******************** TOP OF MAIN LOOP ********************");
  }
  // Capacitive Touch Dynamic Threshold Adjustment
  // Adjust thresholds UP to account for assembly conditions and battery vs usb
  Touch01_Value = touchRead(TCH01_PIN);
  if ( (Touch01_Value / Touch01_Threshold) > 2 ) { Touch01_Threshold = int(Touch01_Threshold * 1.8); }
  Touch02_Value = touchRead(TCH02_PIN);
  if ( (Touch02_Value / Touch02_Threshold) > 2 ) { Touch02_Threshold = int(Touch02_Threshold * 1.8); }
  Touch03_Value = touchRead(TCH03_PIN);
  if ( (Touch03_Value / Touch03_Threshold) > 2 ) { Touch03_Threshold = int(Touch03_Threshold * 1.8); }
  Touch04_Value = touchRead(TCH04_PIN);
  if ( (Touch04_Value / Touch04_Threshold) > 2 ) { Touch04_Threshold = int(Touch04_Threshold * 1.8); }
  Touch05_Value = touchRead(TCH05_PIN);
  if ( (Touch05_Value / Touch05_Threshold) > 2 ) { Touch05_Threshold = int(Touch05_Threshold * 1.8); }

  // //////////////////////////////////
  //     START OF ITERATION LOOP
  // //////////////////////////////////
  //
  // Iterate 0 to 254
  for(int i=0; i<255; i++){
    // Set position value to iteration value
    int pos = i;

    // DEBUG - Print current Iteration value to serial console for troubleshooting
    if (DebugSerial >= 2) {
      Serial.print(" Iteration="); Serial.print(i);
      Serial.print(" Pos="); Serial.print(pos);
    }

    //
    // TOUCH
    //
    // Read Touch Values
    Touch01_Value = touchRead(TCH01_PIN); // Dinosaurs
    Touch02_Value = touchRead(TCH02_PIN); // Logo
    Touch03_Value = touchRead(TCH03_PIN); // 3000
    Touch04_Value = touchRead(TCH04_PIN); // Society
    Touch05_Value = touchRead(TCH05_PIN); // Cowboys
    // **************************************************************
    //
    // Do Stuff If We Detect a Touch on TCH01_PIN
    if (Touch01_Value < Touch01_Threshold) {
      // DEBUG - Print current Touch value/threshold to serial console for troubleshooting
      if (DebugSerial >= 2) {
        Serial.print(" T01_TOUCH="); Serial.print(Touch01_Value);
        Serial.print("/"); Serial.print(Touch01_Threshold);
        Serial.print("-"); Serial.print(Touch01_IntCount);
        Serial.print("/"); Serial.print(Touch01_LoopCount);
      }
      // STUFF - TCH01_PIN TOUCHED
      if (Touch01_IntCount == 0){
        // Put stuff to happen once per iteration loop here
      }
      // Put stuff to happen every iteration here
      Touch01_IntCount = 1;
      touchedDinosaurs();
    //
    // Do Stuff If We DONT Detect a Touch on TCH01_PIN
    } else {
      // DEBUG - Print current Touch value/threshold to serial console for troubleshooting
      if (DebugSerial >= 2) {
        Serial.print(" T01="); Serial.print(Touch01_Value);
        Serial.print("/"); Serial.print(Touch01_Threshold);
        Serial.print("-"); Serial.print(Touch01_IntCount);
        Serial.print("/"); Serial.print(Touch01_LoopCount);
      }
      // STUFF - TCH01_PIN NOT TOUCHED
    }
    // **************************************************************
    //
    // Do Stuff If We Detect a Touch on TCH02_PIN
    if (Touch02_Value < Touch02_Threshold) {
      // DEBUG - Print current Touch value/threshold to serial console for troubleshooting
      if (DebugSerial >= 2) {
        Serial.print(" T02_TOUCH="); Serial.print(Touch02_Value);
        Serial.print("/"); Serial.print(Touch02_Threshold);
        Serial.print("-"); Serial.print(Touch02_IntCount);
        Serial.print("/"); Serial.print(Touch02_LoopCount);
      }
      // STUFF - TCH02_PIN TOUCHED
      if (Touch02_IntCount == 0){
        // Put stuff to happen once per iteration loop here
      }
      // Put stuff to happen every iteration here
      Touch02_IntCount = 1;
    //
    // Do Stuff If We DONT Detect a Touch on TCH02_PIN
    } else {
      // DEBUG - Print current Touch value/threshold to serial console for troubleshooting
      if (DebugSerial >= 2) {
        Serial.print(" T02="); Serial.print(Touch02_Value);
        Serial.print("/"); Serial.print(Touch02_Threshold);
        Serial.print("-"); Serial.print(Touch02_IntCount);
        Serial.print("/"); Serial.print(Touch02_LoopCount);
      }
      // STUFF - TCH02_PIN NOT TOUCHED
    }
    // **************************************************************
    //
    // Do Stuff If We Detect a Touch on TCH03_PIN
    if (Touch03_Value < Touch03_Threshold) {
      // DEBUG - Print current Touch value/threshold to serial console for troubleshooting
      if (DebugSerial >= 2) {
        Serial.print(" T03_TOUCH="); Serial.print(Touch03_Value);
        Serial.print("/"); Serial.print(Touch03_Threshold);
        Serial.print("-"); Serial.print(Touch03_IntCount);
        Serial.print("/"); Serial.print(Touch03_LoopCount);
      }
      // STUFF - TCH03_PIN TOUCHED
      if (Touch03_IntCount == 0){
        // Put stuff to happen once per iteration loop here
      }
      // Put stuff to happen every iteration here
      Touch03_IntCount = 1;
    //
    // Do Stuff If We DONT Detect a Touch on TCH03_PIN
    } else {
      // DEBUG - Print current Touch value/threshold to serial console for troubleshooting
      if (DebugSerial >= 2) {
        Serial.print(" T03="); Serial.print(Touch03_Value);
        Serial.print("/"); Serial.print(Touch03_Threshold);
        Serial.print("-"); Serial.print(Touch03_IntCount);
        Serial.print("/"); Serial.print(Touch03_LoopCount);
      }
      // STUFF - TCH03_PIN NOT TOUCHED
    }
    // **************************************************************
    //
    // Do Stuff If We Detect a Touch on TCH04_PIN
    if (Touch04_Value < Touch04_Threshold) {
      // DEBUG - Print current Touch value/threshold to serial console for troubleshooting
      if (DebugSerial >= 2) {
        Serial.print(" T04_TOUCH="); Serial.print(Touch04_Value);
        Serial.print("/"); Serial.print(Touch04_Threshold);
        Serial.print("-"); Serial.print(Touch04_IntCount);
        Serial.print("/"); Serial.print(Touch04_LoopCount);
      }
      // STUFF - TCH04_PIN TOUCHED
      if (Touch04_IntCount == 0){
        // Put stuff to happen once per iteration loop here
      }
      // Put stuff to happen every iteration here
      Touch04_IntCount = 1;
    //
    // Do Stuff If We DONT Detect a Touch on TCH04_PIN
    } else {
      // DEBUG - Print current Touch value/threshold to serial console for troubleshooting
      if (DebugSerial >= 2) {
        Serial.print(" T04="); Serial.print(Touch04_Value);
        Serial.print("/"); Serial.print(Touch04_Threshold);
        Serial.print("-"); Serial.print(Touch04_IntCount);
        Serial.print("/"); Serial.print(Touch04_LoopCount);
      }
      // STUFF - TCH04_PIN NOT TOUCHED
    }
    // **************************************************************
    //
    // Do Stuff If We Detect a Touch on TCH05_PIN
    if (Touch05_Value < Touch05_Threshold) {
      // DEBUG - Print current Touch value/threshold to serial console for troubleshooting
      if (DebugSerial >= 2) {
        Serial.print(" T05_TOUCH="); Serial.print(Touch05_Value);
        Serial.print("/"); Serial.print(Touch05_Threshold);
        Serial.print("-"); Serial.print(Touch05_IntCount);
        Serial.print("/"); Serial.print(Touch05_LoopCount);
      }
      // STUFF - TCH05_PIN TOUCHED
      if (Touch05_IntCount == 0){
        // Put stuff to happen once per iteration loop here
      }
      // Put stuff to happen every iteration here
      Touch05_IntCount = 1;
      touchedCowboys();
    //
    // Do Stuff If We DONT Detect a Touch on TCH05_PIN
    } else {
      // DEBUG - Print current Touch value/threshold to serial console for troubleshooting
      if (DebugSerial >= 2) {
        Serial.print(" T05="); Serial.print(Touch05_Value);
        Serial.print("/"); Serial.print(Touch05_Threshold);
        Serial.print("-"); Serial.print(Touch05_IntCount);
        Serial.print("/"); Serial.print(Touch05_LoopCount);
      }
      // STUFF - TCH05_PIN NOT TOUCHED
    }

    //
    // DEFAULT MODE
    //
    // First of three position groups i 0-84
    if (pos < 85) {
      //
      // LED FUNCTIONS
      table_neo_colorshift(pos, 1);
      threeks_neo_colorshift(pos, 1);
      ledPwmAlternate(pos, 1);
      BI_blink_two(pos);
    // Second of three position groups i 85-169 (pos-85 = 0-84)
    } else if (pos < 170) {
      pos = pos - 85;
      //
      // LED FUNCTIONS
      table_neo_colorshift(pos, 2);
      threeks_neo_colorshift(pos, 2);
      ledPwmAlternate(pos, 2);
      BI_blink_two(pos);
    // Third of three position groups i 170-254 (pos-170 = 0-84)
    } else {
      pos = pos -170;
      //
      // LED FUNCTIONS
      table_neo_colorshift(pos, 3);
      threeks_neo_colorshift(pos, 3);
      BI_blink_two(pos);
      // Split third group 3/4 (pos 0-42) for even number of transitions
      if (pos <43) {
        //
        ledPwmAlternate(pos, 3);
      // Split third group 4/4 (pos 43-84) for even number of transitions
      } else {
        //
        ledPwmAlternate(pos, 4);
      }
    }

    // DEBUG - Print status neopixel mode
    if (DebugSerial >= 2) {
      // Status NeoPixel LED color mode default=0 green=1 blue=2 red=3
      Serial.print(" Smode="); Serial.print(status_neo_mode);
    }

    // DEBUG - Print Carriage Return for iteration level debug output
    if (DebugSerial >= 2) {
      Serial.println();
    }

    // Display Neopixel values
    neo_show();

    // Pause the loop to display everything
    delay(LEDDelayTime);

    // END OF FOR ITERATION LOOP
  }
  // //////////////////////////////////
  //     END OF ITERATION LOOP
  // //////////////////////////////////

  // Touch Loop Counters - USE TBD
  if (Touch01_IntCount == 1) { Touch01_LoopCount++; Touch01_IntCount = 0; } else { Touch01_LoopCount = 0; }
  if (Touch02_IntCount == 1) { Touch02_LoopCount++; Touch02_IntCount = 0; } else { Touch02_LoopCount = 0; }
  if (Touch03_IntCount == 1) { Touch03_LoopCount++; Touch03_IntCount = 0; } else { Touch03_LoopCount = 0; }
  if (Touch04_IntCount == 1) { Touch04_LoopCount++; Touch04_IntCount = 0; } else { Touch04_LoopCount = 0; }
  if (Touch05_IntCount == 1) { Touch05_LoopCount++; Touch05_IntCount = 0; } else { Touch05_LoopCount = 0; }

  // Turn off all LEDs at end of loop (Optional)
  // ledAllOff();

  // //////////////////////////////////////////////////
  //
  // Launch REACTION TIME GAME Alternate Mainline Code When
  // Touch01_LoopCount exceeds Touch01_Loop_Threshold
  //
  // //////////////////////////////////////////////////
  if (Touch01_LoopCount > Touch01_Loop_Threshold) {
    //
    Serial.println("LONG TOUCH DETECTED on TCH01 - JUMP TO ALTERNATE CODE");
    //
    ledAllOff();
    //
    Touch01_LoopCount = 0;
    //
    // Alternate code loop
    reaction_time_game();
    //
    // END ALTERNATE MAIN LOOP
    Serial.println("****************************************");
    Serial.println("****** EXITING REACTION TIME GAME ******");
    Serial.println("****************************************");
    //
    ledAllOff();
    //
    Touch01_LoopCount = 0;
    //
    status_neo_mode = 0;
    // Pause before exiting
    delay(100);
  }

  // //////////////////////////////////////////////////
  //
  // Launch BATT_CHRG_NOLED Alternate Mainline Code When
  // Touch02_LoopCount exceeds Touch02_Loop_Threshold
  //
  // //////////////////////////////////////////////////
  if (Touch02_LoopCount > Touch02_Loop_Threshold) {
    //
    Serial.println("LONG TOUCH DETECTED on TCH02 - JUMP TO ALTERNATE CODE");
    //
    ledAllOff();
    //
    Touch02_LoopCount = 0;
    //
    // Alternate code loop
    batt_chrg_noled();
    //
    // END ALTERNATE MAIN LOOP
    Serial.println("****************************************");
    Serial.println("***** EXITING BATT_CHRG_NOLED MODE *****");
    Serial.println("****************************************");
    //
    ledAllOff();
    //
    Touch02_LoopCount = 0;
    //
    status_neo_mode = 0;
    // Pause before exiting
    delay(100);
  }

  // //////////////////////////////////////////////////
  //
  // Launch FLUSH CARD GAME Alternate Mainline Code When
  // Touch05_LoopCount exceeds Touch05_Loop_Threshold
  //
  // //////////////////////////////////////////////////
  if (Touch05_LoopCount > Touch05_Loop_Threshold) {
    //
    Serial.println("LONG TOUCH DETECTED on TCH05 - JUMP TO ALTERNATE CODE");
    //
    ledAllOff();
    //
    Touch05_LoopCount = 0;
    //
    // Alternate code loop
    flush_card_game();
    //
    // END ALTERNATE MAIN LOOP
    Serial.println("****************************************");
    Serial.println("***** EXITING FLUSH CARD GAME MODE *****");
    Serial.println("****************************************");
    //
    ledAllOff();
    //
    Touch05_LoopCount = 0;
    //
    status_neo_mode = 0;
    // Pause before exiting
    delay(100);
  }

}
// //////////////////////////////////
//        END OF MAIN LOOP
// //////////////////////////////////


// //////////////////////////////////////////////////
//
// FUNCTIONS
//
// //////////////////////////////////////////////////
//
// WiFi & BT Functions
// //////////////////////////////////////////////////
void disableWiFi(){
    WiFi.disconnect(true);  // Disconnect from the network
    WiFi.mode(WIFI_OFF);    // Switch WiFi off
    Serial.println("WiFi disabled!");
}
//
void disableBluetooth(){
    btStop();
    Serial.println("Bluetooth stopped!");
}
//
void setModemSleep() {
    disableWiFi();
    disableBluetooth();
    setCpuFrequencyMhz(80);
}
//
void enableWiFi(){
    delay(200);
    // Switch Wifi ON in mode AP/STA/AP_STA
    WiFi.mode(WIFI_AP); // Defaulting to AP mode
    delay(200);
    Serial.println("WiFi Started!");
}
//
void wakeModemSleep() {
    setCpuFrequencyMhz(240);
    enableWiFi();
}
// //////////////////////////////////////////////////
//
// LED Functions
// //////////////////////////////////////////////////
void ledAllOff() {
  digitalWrite(LED_BI, HIGH); // HIGH = OFF?
  ledcWrite(LED_D1_pwm, 0);
  ledcWrite(LED_D2_pwm, 0);
  ledcWrite(LED_D3_pwm, 0);
  ledcWrite(LED_D4_pwm, 0);
  ledcWrite(LED_D5_pwm, 0);
  ledcWrite(LED_D6_pwm, 0);
  NEO01.setPixelColor(0, 0, 0, 0);
  NEO01.setPixelColor(1, 0, 0, 0);
  NEO01.setPixelColor(2, 0, 0, 0);
  NEO01.show();
  NEO02.setPixelColor(0, 0, 0, 0);
  NEO02.setPixelColor(1, 0, 0, 0);
  NEO02.setPixelColor(2, 0, 0, 0);
  NEO02.show();
}
//
void ledPwmAllOn() {
    ledcWrite(LED_D1_pwm, 255);
    ledcWrite(LED_D3_pwm, 255);
    ledcWrite(LED_D5_pwm, 255);
    ledcWrite(LED_D2_pwm, 255);
    ledcWrite(LED_D4_pwm, 255);
    ledcWrite(LED_D6_pwm, 255);
}
//
void ledPwmAllOff() {
    ledcWrite(LED_D1_pwm, 0);
    ledcWrite(LED_D3_pwm, 0);
    ledcWrite(LED_D5_pwm, 0);
    ledcWrite(LED_D2_pwm, 0);
    ledcWrite(LED_D4_pwm, 0);
    ledcWrite(LED_D6_pwm, 0);
}
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

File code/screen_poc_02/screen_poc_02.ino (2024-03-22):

// screen_poc_02
//
// code to test the GC9A01A screen on the esp dev board
// steps through various different screen write types
// code borrowed from Adafruit examples
//
// POC PINOUT
//
// ESP32 <->  TFT
// --------------
//  3V3  <->  VCC
//  GND  <->  GND
//   18  <->  SCL
//   23  <->  SDA
//   16  <->  DC
//    5  <->  CS
//    4  <->  RST
//
#include "SPI.h"
#include "Adafruit_GFX.h"
#include "Adafruit_GC9A01A.h"

// Define pins for display interface. You'll probably need to edit this for
// your own needs:

//#if defined(ARDUINO_SEEED_XIAO_RP2040)
// Pinout when using Seed Round Display for XIAO in combination with
// Seeed XIAO RP2040. Other (non-RP2040) XIAO boards, any Adafruit Qt Py
// boards, and other GC9A01A display breakouts will require different pins.
//#define TFT_CS D1 // Chip select
//#define TFT_DC D3 // Data/command
//#define TFT_BL D6 // Backlight control
//#else // ALL OTHER BOARDS - EDIT AS NEEDED
// Other RP2040-based boards might not have "D" pin defines as shown above
// and will use GPIO bit numbers. On non-RP2040 boards, you can usually use
// pin numbers silkscreened on the board.
#define TFT_DC 16
#define TFT_CS 5
// If display breakout has a backlight control pin, that can be defined here
// as TFT_BL. On some breakouts it's not needed, backlight is always on.
//#define TFT_BL 6
//#endif

// Display constructor for primary hardware SPI connection -- the specific
// pins used for writing to the display are unique to each board and are not
// negotiable. "Soft" SPI (using any pins) is an option but performance is
// reduced; it's rarely used, see header file for syntax if needed.
Adafruit_GC9A01A tft(TFT_CS, TFT_DC);

void setup() {
  Serial.begin(9600);
  Serial.println("GC9A01A Test!");

  tft.begin();

#if defined(TFT_BL)
  pinMode(TFT_BL, OUTPUT);
  digitalWrite(TFT_BL, HIGH); // Backlight on
#endif // end TFT_BL

  Serial.println(F("Benchmark                Time (microseconds)"));
  delay(10);
  Serial.print(F("Screen fill              "));
  Serial.println(testFillScreen());
  delay(500);

  Serial.print(F("Text                     "));
  Serial.println(testText());
  delay(3000);

  Serial.print(F("Lines                    "));
  Serial.println(testLines(GC9A01A_CYAN));
  delay(500);

  Serial.print(F("Horiz/Vert Lines         "));
  Serial.println(testFastLines(GC9A01A_RED, GC9A01A_BLUE));
  delay(500);

  Serial.print(F("Rectangles (outline)     "));
  Serial.println(testRects(GC9A01A_GREEN));
  delay(500);

  Serial.print(F("Rectangles (filled)      "));
  Serial.println(testFilledRects(GC9A01A_YELLOW, GC9A01A_MAGENTA));
  delay(500);

  Serial.print(F("Circles (filled)         "));
  Serial.println(testFilledCircles(10, GC9A01A_MAGENTA));

  Serial.print(F("Circles (outline)        "));
  Serial.println(testCircles(10, GC9A01A_WHITE));
  delay(500);

  Serial.print(F("Triangles (outline)      "));
  Serial.println(testTriangles());
  delay(500);

  Serial.print(F("Triangles (filled)       "));
  Serial.println(testFilledTriangles());
  delay(500);

  Serial.print(F("Rounded rects (outline)  "));
  Serial.println(testRoundRects());
  delay(500);

  Serial.print(F("Rounded rects (filled)   "));
  Serial.println(testFilledRoundRects());
  delay(500);

  Serial.println(F("Done!"));
}

void loop(void) {
  for(uint8_t rotation=0; rotation<5; rotation++) {
    tft.setRotation(rotation);
    testText();
    delay(1000);
  }
  delay(100);

  testFillScreen();
  delay(800);

  testLines(GC9A01A_CYAN);
  delay(800);

  testFastLines(GC9A01A_RED, GC9A01A_BLUE);
  delay(800);

  testRects(GC9A01A_GREEN);
  delay(800);

  testFilledRects(GC9A01A_YELLOW, GC9A01A_MAGENTA);
  delay(800);

  testFilledCircles(10, GC9A01A_MAGENTA);
  delay(800);

  testCircles(10, GC9A01A_WHITE);
  delay(800);

  testTriangles();
  delay(800);

  testFilledTriangles();
  delay(800);

  testRoundRects();
  delay(800);

  testFilledRoundRects();
  delay(800);
}

unsigned long testFillScreen() {
  unsigned long start = micros();
  tft.fillScreen(GC9A01A_BLACK);
  yield();
  tft.fillScreen(GC9A01A_RED);
  yield();
  tft.fillScreen(GC9A01A_GREEN);
  yield();
  tft.fillScreen(GC9A01A_BLUE);
  yield();
  tft.fillScreen(GC9A01A_BLACK);
  yield();
  return micros() - start;
}

unsigned long testText() {
  tft.fillScreen(GC9A01A_BLACK);
  unsigned long start = micros();
  tft.setCursor(0, 0);
  tft.setTextColor(GC9A01A_WHITE);  tft.setTextSize(1);
  tft.println("Hello World!");
  tft.setTextColor(GC9A01A_YELLOW); tft.setTextSize(2);
  tft.println(1234.56);
  tft.setTextColor(GC9A01A_RED);    tft.setTextSize(3);
  tft.println(0xDEADBEEF, HEX);
  tft.println();
  tft.setTextColor(GC9A01A_GREEN);
  tft.setTextSize(5);
  tft.println("Groop");
  tft.setTextSize(2);
  tft.println("I implore thee,");
  tft.setTextSize(1);
  tft.println("my foonting turlingdromes.");
  tft.println("And hooptiously drangle me");
  tft.println("with crinkly bindlewurdles,");
  tft.println("Or I will rend thee");
  tft.println("in the gobberwarts");
  tft.println("with my blurglecruncheon,");
  tft.println("see if I don't!");
  return micros() - start;
}

unsigned long testLines(uint16_t color) {
  unsigned long start, t;
  int           x1, y1, x2, y2,
                w = tft.width(),
                h = tft.height();

  tft.fillScreen(GC9A01A_BLACK);
  yield();

  x1 = y1 = 0;
  y2    = h - 1;
  start = micros();
  for(x2=0; x2<w; x2+=6) tft.drawLine(x1, y1, x2, y2, color);
  x2    = w - 1;
  for(y2=0; y2<h; y2+=6) tft.drawLine(x1, y1, x2, y2, color);
  t     = micros() - start; // fillScreen doesn't count against timing

  yield();
  tft.fillScreen(GC9A01A_BLACK);
  yield();

  x1    = w - 1;
  y1    = 0;
  y2    = h - 1;
  start = micros();
  for(x2=0; x2<w; x2+=6) tft.drawLine(x1, y1, x2, y2, color);
  x2    = 0;
  for(y2=0; y2<h; y2+=6) tft.drawLine(x1, y1, x2, y2, color);
  t    += micros() - start;

  yield();
  tft.fillScreen(GC9A01A_BLACK);
  yield();

  x1    = 0;
  y1    = h - 1;
  y2    = 0;
  start = micros();
  for(x2=0; x2<w; x2+=6) tft.drawLine(x1, y1, x2, y2, color);
  x2    = w - 1;
  for(y2=0; y2<h; y2+=6) tft.drawLine(x1, y1, x2, y2, color);
  t    += micros() - start;

  yield();
  tft.fillScreen(GC9A01A_BLACK);
  yield();

  x1    = w - 1;
  y1    = h - 1;
  y2    = 0;
  start = micros();
  for(x2=0; x2<w; x2+=6) tft.drawLine(x1, y1, x2, y2, color);
  x2    = 0;
  for(y2=0; y2<h; y2+=6) tft.drawLine(x1, y1, x2, y2, color);

  yield();
  return micros() - start;
}

unsigned long testFastLines(uint16_t color1, uint16_t color2) {
  unsigned long start;
  int           x, y, w = tft.width(), h = tft.height();

  tft.fillScreen(GC9A01A_BLACK);
  start = micros();
  for(y=0; y<h; y+=5) tft.drawFastHLine(0, y, w, color1);
  for(x=0; x<w; x+=5) tft.drawFastVLine(x, 0, h, color2);

  return micros() - start;
}
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

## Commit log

2024-03-11 initial badge template
    [BatteryHolder_2466_1xAAA.step, BatteryHolder_2468_2xAAA.step, Battery_Holder_3xAAA_Simple.step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]
2024-03-18 added ESP32 Wemos Lolin32 Lite schem footprints 3D
2024-03-25 footprint and schem updates
2024-03-25 footprint and schematic updates
2024-03-27 schematic anf footprint work
2024-03-27 esp footprint update
2024-04-02 schematic and poc test work
    [cowboys_vs_dinos.kicad_sch]
2024-04-09 schematic work
2024-04-17 updated footprints
2024-04-29 pcb edge cuts
    [cowboys_vs_dinos.kicad_pcb]
2024-04-30 art and pcb edge work
    [cowboys_vs_dinos.kicad_pcb]
2024-05-01 center art
    [cowboys_vs_dinos.kicad_sch]
2024-05-01 more art and pcb work
2024-05-04 art and eda layout work
    [cowboys_vs_dinos.kicad_sch]
2024-05-06 pcb layout updates
    [cowboys_vs_dinos.kicad_sch]
2024-05-06 more pcb work
2024-05-06 ready for manufacturing
    [cowboys_vs_dinos-B_Cu.gbl, cowboys_vs_dinos-B_Mask.gbs, cowboys_vs_dinos-B_Paste.gbp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]
2024-06-28 add 3d models for printing the Bumper
    [dc32_cowbows_dinosaurs_bumper.step, dc32_cowbows_dinosaurs_bumper.stl]
2024-06-30 assembly instructions

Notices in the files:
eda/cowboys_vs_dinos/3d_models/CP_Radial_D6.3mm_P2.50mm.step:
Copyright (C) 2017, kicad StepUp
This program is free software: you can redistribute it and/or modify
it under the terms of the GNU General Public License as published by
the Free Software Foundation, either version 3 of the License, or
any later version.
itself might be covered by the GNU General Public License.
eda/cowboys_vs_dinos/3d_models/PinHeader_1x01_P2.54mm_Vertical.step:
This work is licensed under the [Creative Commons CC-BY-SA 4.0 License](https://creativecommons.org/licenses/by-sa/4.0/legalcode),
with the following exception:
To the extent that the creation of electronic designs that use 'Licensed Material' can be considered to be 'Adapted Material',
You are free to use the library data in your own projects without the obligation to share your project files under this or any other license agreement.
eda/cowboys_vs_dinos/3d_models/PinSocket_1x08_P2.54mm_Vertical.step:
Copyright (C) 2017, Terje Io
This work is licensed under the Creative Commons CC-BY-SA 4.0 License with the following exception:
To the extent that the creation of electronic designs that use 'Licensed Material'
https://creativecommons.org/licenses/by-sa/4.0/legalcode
